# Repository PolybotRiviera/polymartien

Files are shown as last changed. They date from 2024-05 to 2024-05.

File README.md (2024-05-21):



Repo of the robotics project, 2024 edition: Farming Mars,
from the Polytech Nice Sophia robotics team!
## Objectives
The purpose of the robot is to carry out several tasks in complete autonomy. The tasks to be performed are as follows:
- Pick up different types of plant

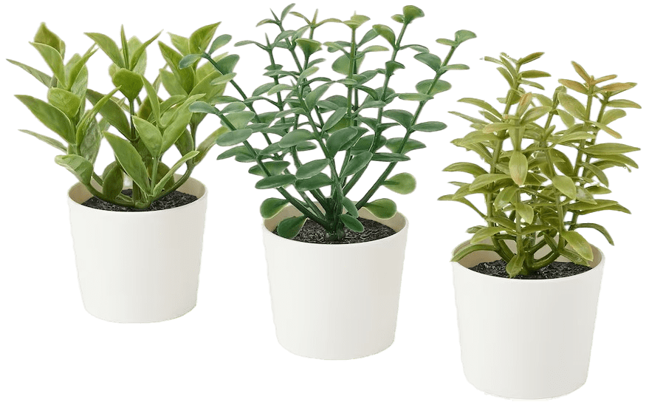
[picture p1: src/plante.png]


- Place plants in pots

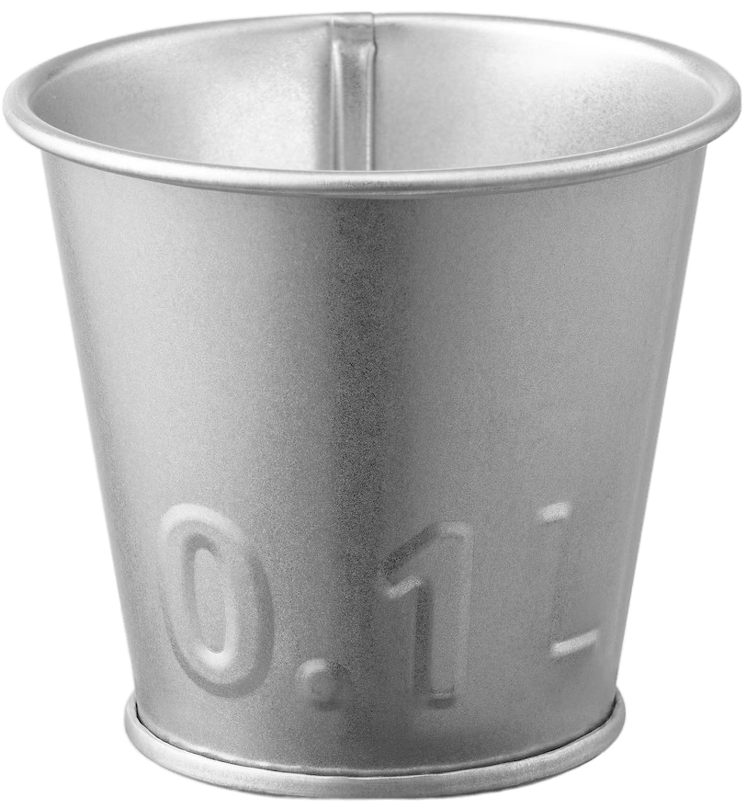
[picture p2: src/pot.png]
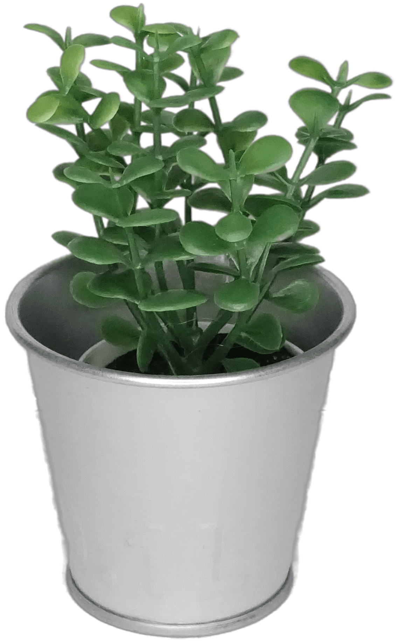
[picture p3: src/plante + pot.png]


- Bring plants to a predefined area

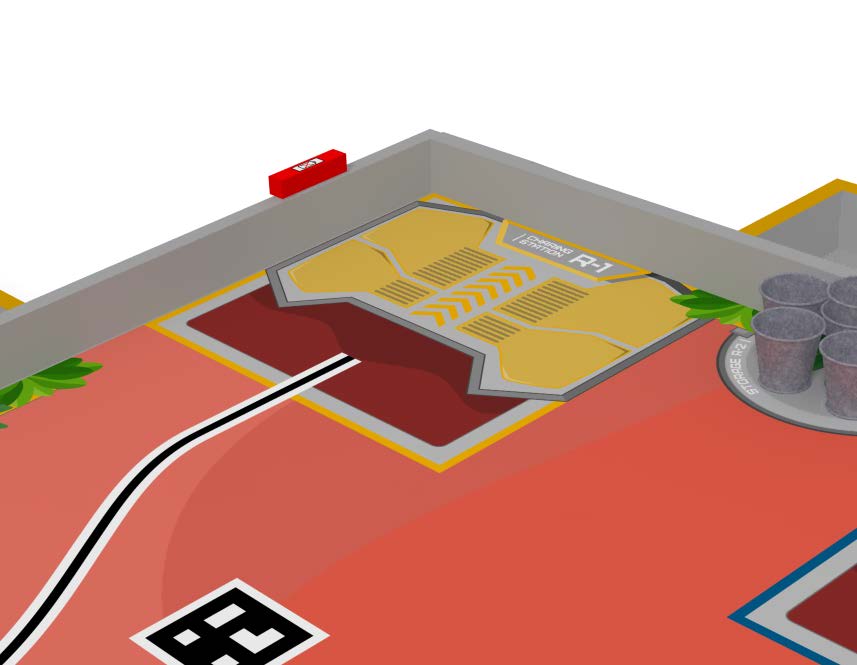
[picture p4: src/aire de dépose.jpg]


- Sort plants by type

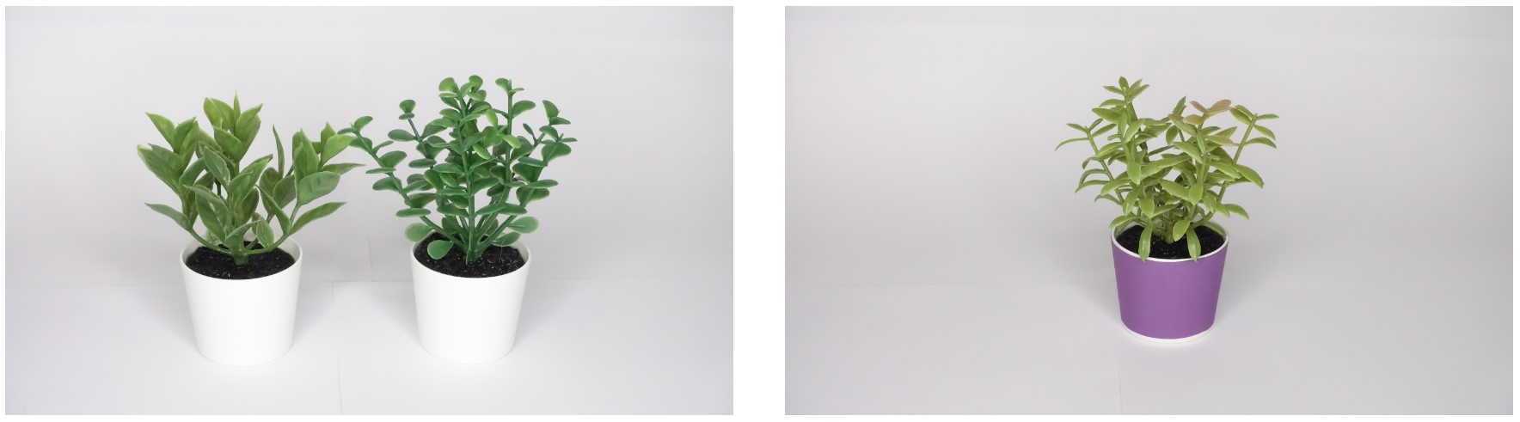
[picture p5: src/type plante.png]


> Two fragile plants, one resistant plant

- Orienting solar panels

All the work must be completed within the allotted time and without colliding with the environment (walls, other robots, plants, pots).

## constraints
- Robot dimensions :
    - Perimeter between 1200 and 1300 mm

    
    
    - Height under 350 mm

## Main components
- Chassis / Rolling base
- Gripper system (rail-mounted gripper)
- Vision systems (cameras, sensors)
- Storage system (turntable)

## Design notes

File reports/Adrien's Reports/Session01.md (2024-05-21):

# Session Report 1:

**Session Objective:** Mount the received DC motors on the prototype, test them, and determine parameters useful for the robot's control.

During this session, we assembled the motors and wheels on the base so that I could initiate the control and odometry of the robot.

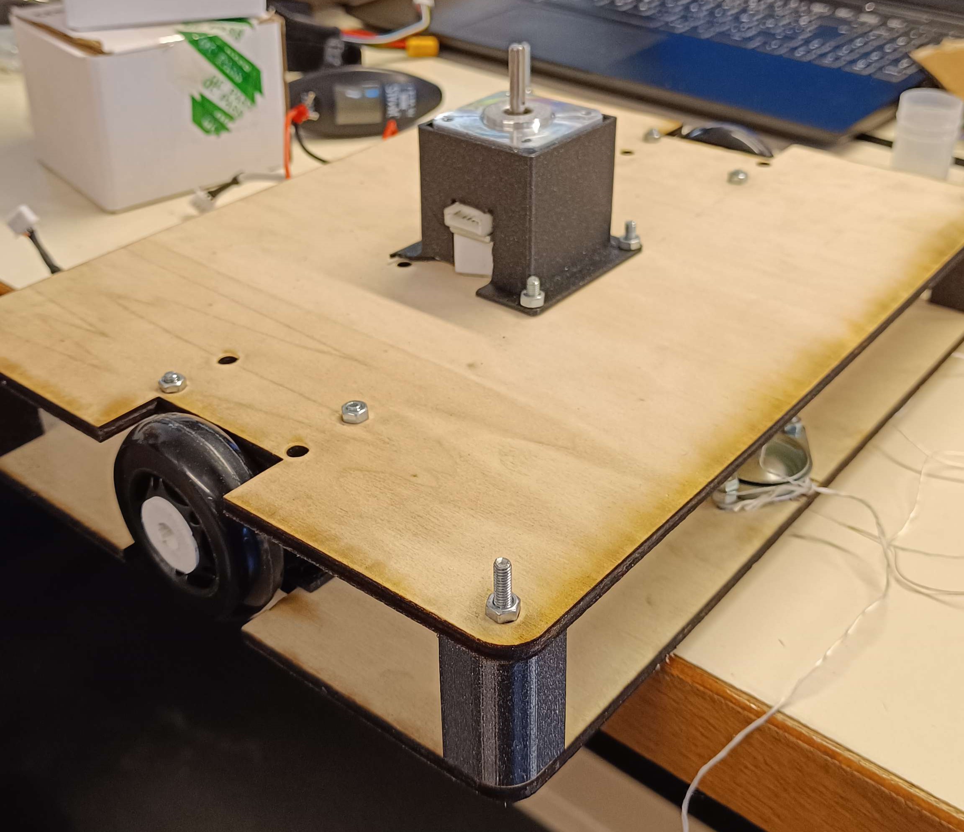
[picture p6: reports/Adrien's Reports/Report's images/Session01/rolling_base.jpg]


## Changes to the Rolling Base:
As mentioned in the project bibliography, the new version of our U-shaped robot has a large empty space in the center to collect plants in large quantities. This efficiency gain adds a significant constraint: we are now obliged to place the motors at the rear of the robot, as shown in the model created by Loïc below.

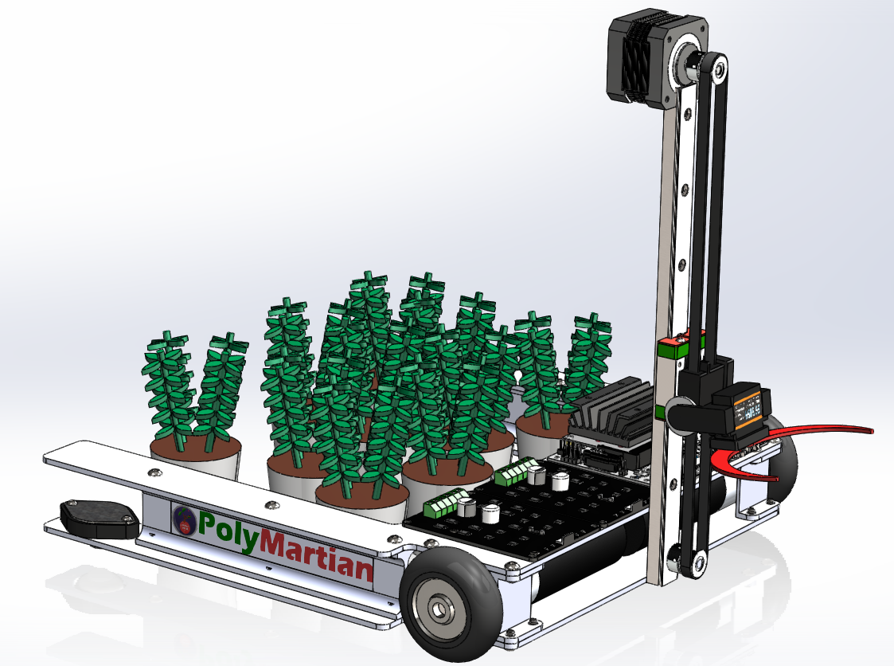
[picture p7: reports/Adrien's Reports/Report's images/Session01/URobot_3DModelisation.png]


However, for the robot to move easily and quickly avoid the opponent robot, it is preferable for the robot to be able to rotate on itself, and therefore have its wheels placed in the middle. Thus, we decided to shift the wheels by transmitting the rotation of the motors placed at the back of the robot to the wheels in the middle using belts.

My research also led me to realize that it would be risky to place encoders directly on the motor axes for robot odometry (i.e., to know its position based on the number of wheel rotations). In the event of robot slippage, the encoder may not be incremented even though the robot has moved, causing a drift in our estimation compared to the actual position. That's why many teams opt for encoder wheels. This involves placing encoders on free wheels parallel to the drive wheels. These free wheels are fixed via a pivot link so that the wheel can always remain in contact with the ground. Finally, the narrower the encoder wheels, the higher the odometry precision will be.

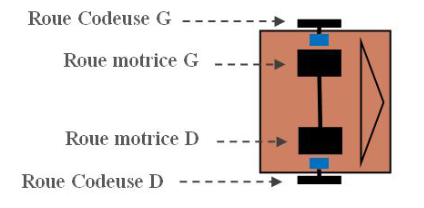
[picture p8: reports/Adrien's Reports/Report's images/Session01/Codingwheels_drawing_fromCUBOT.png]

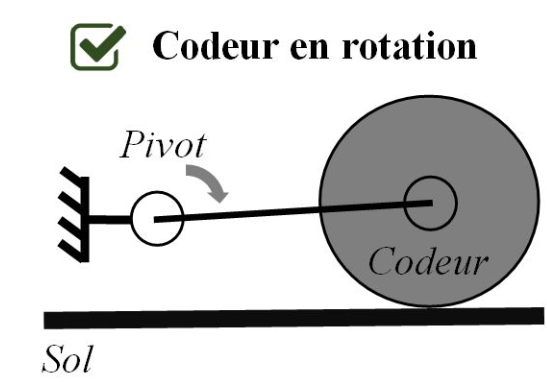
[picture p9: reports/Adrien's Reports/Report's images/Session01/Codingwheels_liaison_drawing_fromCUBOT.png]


(Images Source : Cubot Team)

## Assembly and testing of motors and wheels, and encountered problems:
We were able to test our motors by connecting them using Cytron 13A CC Driver Cards and 12V Power supply.

This revealed a first problem: at high speed, the wheels shake perpendicular to the wheel plane. The most probable hypotheses are that this is due to wheel warping. We ordered roller wheels for good grip, but no precision information is provided on manufacturing tolerance. This will be verified with a comparator before the next session. Another possibility is that the motor axis is not perfectly perpendicular to the wheel axis. Finally, play within the motor can also be the cause, but it is much less than the rotation play of the wheel.

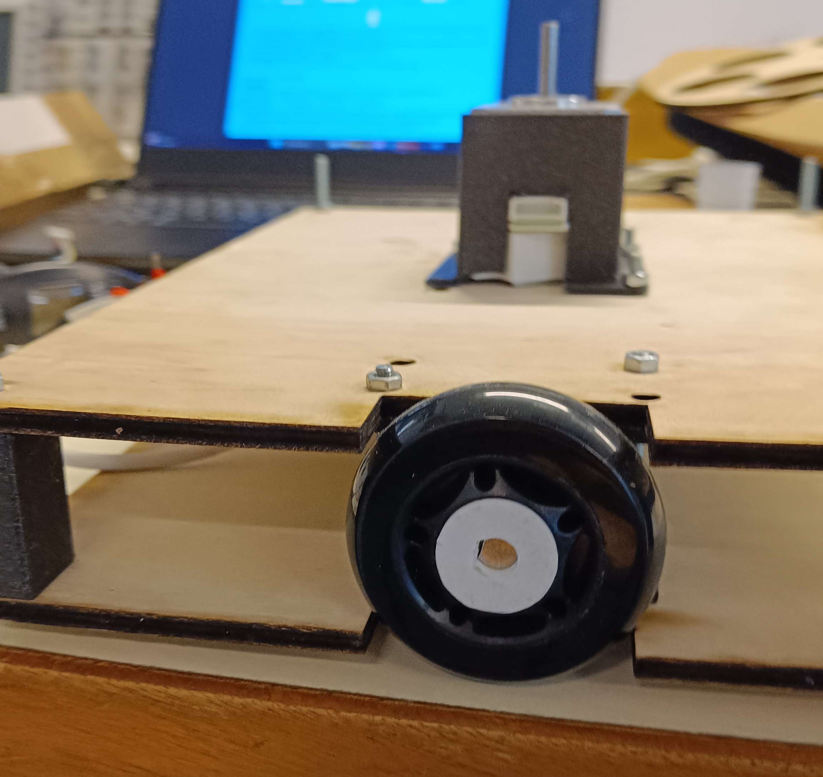
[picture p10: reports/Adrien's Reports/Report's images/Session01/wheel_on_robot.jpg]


## Control: Calculation of the coefficient of adhesion between the wheels and the table.

During this second part of the session, I sought to calculate the coefficient of adhesion of our wheels on the game table to use it in our control parameters. This will be essential (in addition to the center of gravity of the robot) to calculate very precisely the acceleration limit not to exceed under the risk of slipping. Indeed, to optimize acceleration and braking phases, the robot must be at all times at the slipping limit, considering a safety margin.
To measure this coefficient very precisely, the suspended bucket method can be used. This method simply requires a bucket, a pulley, a rope, and a scale.


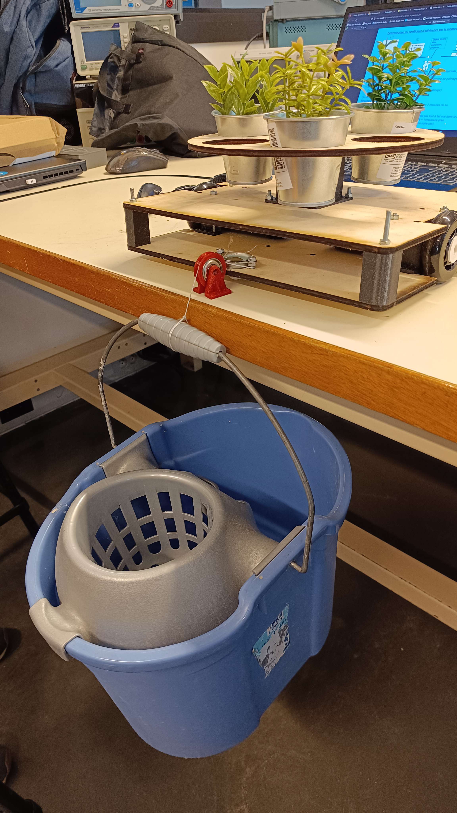
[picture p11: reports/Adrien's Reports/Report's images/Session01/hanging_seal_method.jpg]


It consists of attaching one end of the rope to the base of the robot placed on the table (as close as possible to the base), and the other end to a bucket suspended in the void by passing the rope through a pulley fixed to the end of the table. For this, we simply made a pulley using three 3D-printed pieces and a ball bearing. We then mechanically block the wheels, in our case simply using screwdrivers between the base and the outer surfaces of the wheels. The bucket is then filled with different objects serving as weights to apply a horizontal force on the robot.
To calculate this coefficient, proceed as follows:

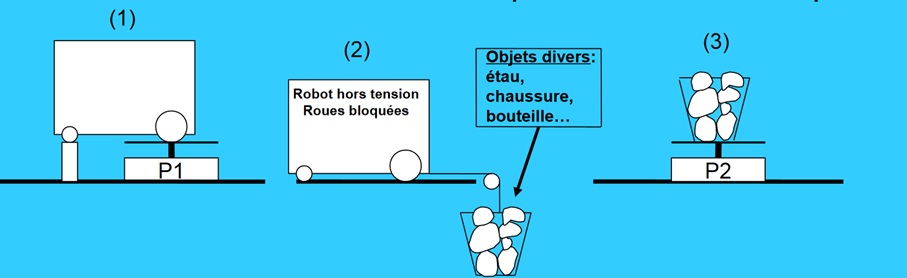
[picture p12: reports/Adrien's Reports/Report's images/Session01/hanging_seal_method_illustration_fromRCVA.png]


(Image Source : RCVA Team)

- Measure the support force of the drive wheels on the ground by placing the robot wheels on a scale while keeping it horizontal with a wedge under the free wheel. Note this mass P1.
- Measure the mass of the objects in the bucket from which the robot is at the slipping limit, i.e., the force required to slide the robot with the wheels blocked. Note this mass P2.
- Finally, the coefficient is simply Ka = P2/P1.

Due to measurement inaccuracies (due to the choice of weights), you can calculate both the robot's adhesion coefficient unloaded and loaded and keep the average of the two. Indeed, the coefficient of adhesion is theoretically the same unloaded and loaded.

Having received the official vinyl game mat, we wanted to calculate the coefficient of adhesion between the wheels and the mat during this session. 

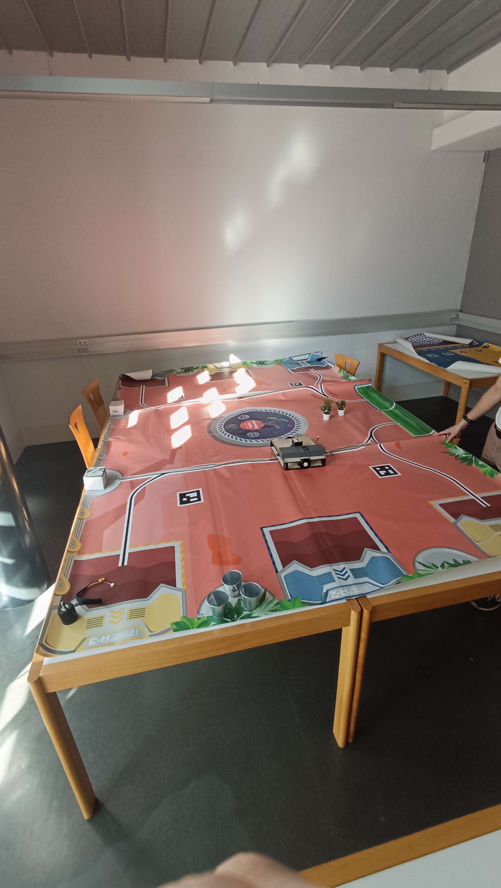
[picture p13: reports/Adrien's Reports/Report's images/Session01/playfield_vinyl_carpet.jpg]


However, our scale was limited to loads of 2 kg, so we have to postpone this calculation to later. However, this allowed us to observe the very strong adhesion of the roller wheels on the vinyl and to manufacture the suspended bucket system that will be used later.

## Sources:

    http://www.rcva.fr/wp-content/uploads/2016/12/devoir_de_vacances.pdf
    https://github.com/VRAC-team/la-maxi-liste-ressourceseurobot/blob/master/asservissement/Cubot-atelier_asservissement.pdf

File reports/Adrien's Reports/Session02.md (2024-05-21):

# Session report 2:

**Session objective:** Complete research on the most crucial physics constraints to consider in achieving a reliable rolling base for the prototyping of the next version. And begin work on the closed-loop control.

## Steps to implement odometry and feedback control 

First of all, I established an ordered list of my next tasks to do to enhance efficiency:

1) Ensure a high-performance mechanical system with optimal weight distribution, reliable coding wheels, and precise wheel placement. This aspect was thoroughly considered since we started the first session. We have now identified an excellent implementation, and Loic is currently working on the mechanical part.
2) Calibrate the odometry to determine the precise location of the robot on the table using the coding wheels. This system relies on four constants: coding wheel diameters, their spacing, encoder resolution, and the error related to the diameter difference between the two coding wheels.
3) Send a command and calculate errors between it and the estimated position based on the odometry.
4) Implement ramps to achieve progressive acceleration and deceleration.
5) Implement a PID (Proportional Integral Derivative) control system: Identify the optimal coefficients for Proportional, Integral, and Derivative terms to reach a value very close to the setpoint rapidly and without excessive oscillations.

As the coding wheels are still in the design phase, I have decided to prioritize continuing work on determining the maximum acceleration. This way, this aspect will be prepared for implementation once the rolling base is ready to conduct physics measurements.

## Measuring the buckling of the wheels and the play in the motor.

During the previous session, we observed lateral vibrations in the wheels. Therefore, this time, using a dial indicator, I measured the buckling of the wheels.

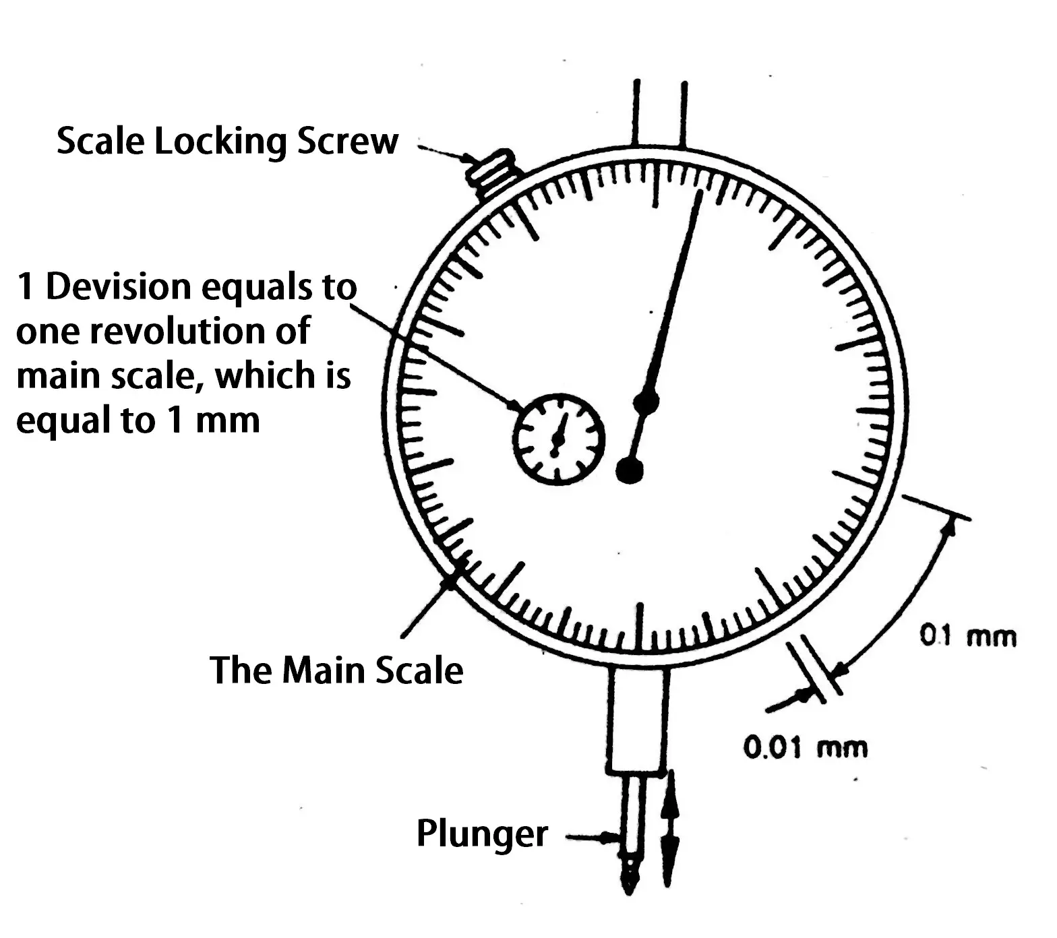
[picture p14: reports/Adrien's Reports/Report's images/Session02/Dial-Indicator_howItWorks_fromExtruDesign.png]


To use this tool, we have to magnetize it to a fixed surface to prevent shaking. Then, we simply position the plunger against the external surface of the wheel. Next, we delicately turn the wheel one complete revolution (or multiple turns for more precision). Afterward, we read the buckling on the graduated scale and divide it by the number of turns made. The precision of this instrument is approximately 0.01mm, which corresponds to the space between two marks on the scale.

With this tool, I measured a buckling of approximately 1mm per wheel, which is not insignificant but much less than I expected. Therefore, I believe it won't pose a significant obstacle to achieving precise odometry at the outset. That's why we have decided to retain these wheels, and we will consider replacing them with more precise ones only if they prove inadequate results.

## Encoder and reflections on coding wheels

Since the encoders attached to the ends of our motor shafts are now no longer needed due to the use of coding wheels. I have contemplated a way to repurpose these encoders by placing them in front of the metal shafts of the coding wheels to avoid buying new ones. By disassembling one, I observed that we could easily reduce the total length of the motor + gearbox assembly to position the wheels more toward the inside. This will allow us to align the coding wheels in parallel on the extremities of the robot. Indeed, the greater the spacing between the coding wheels, the more precise our angle reading during rotation will be. Additionally, since the encoder is a Hall effect sensor, we can easily reuse it by placing the hall sensor directly in front of the axes of our rotary encoders.

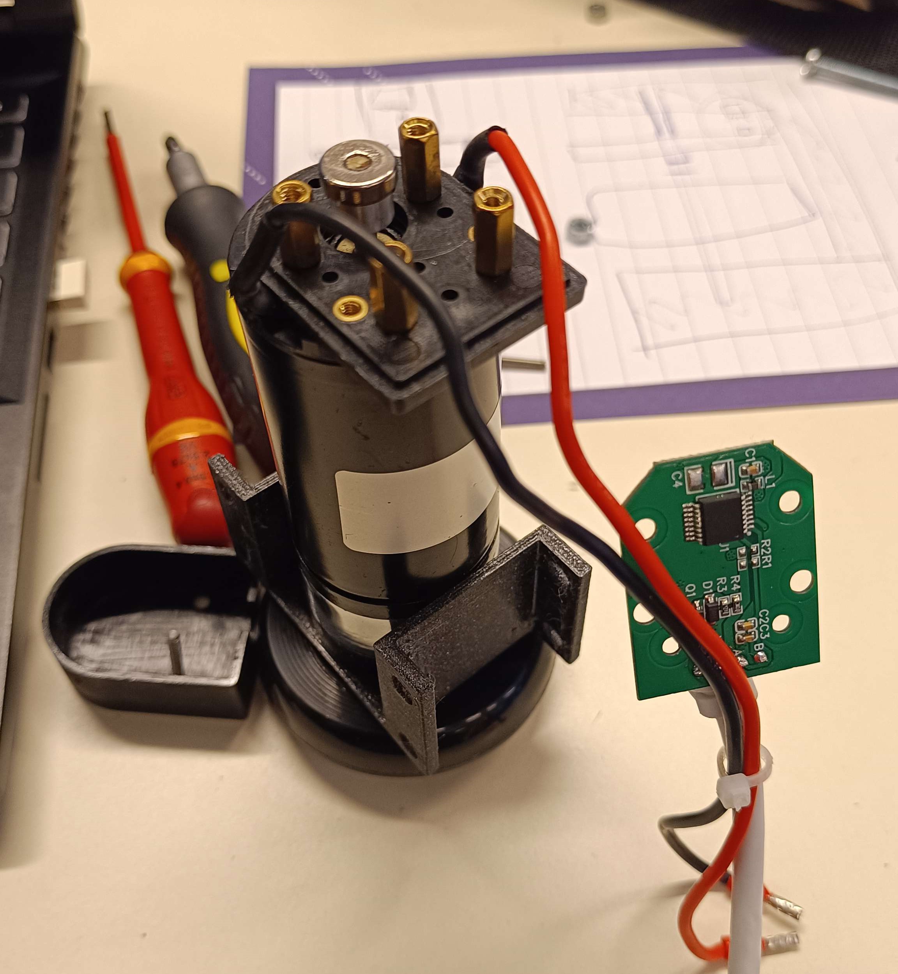
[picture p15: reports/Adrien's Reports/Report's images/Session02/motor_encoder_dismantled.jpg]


During this session, I also learned that a minuscule diameter difference between the two coding wheels can result in significant imprecision. Cause if the coding wheels register the same number of revolutions, it will lead us to believe that the robot is moving in a straight line. However, in reality, if one wheel has a smaller diameter, the robot will veer to one side.

And as we integrate small displacements of the robot to determine the position from a reference point. We will accumulate erros over time which will be source to a lack of precision.

To address this issue, we need to implement a coefficient to multiply the number of revolutions of one wheel by a certain factor. This compensates for the diameter difference, ensuring that both wheels cover an equal distance and register the correct movement.

## New conception for the rolling base with its coding wheels

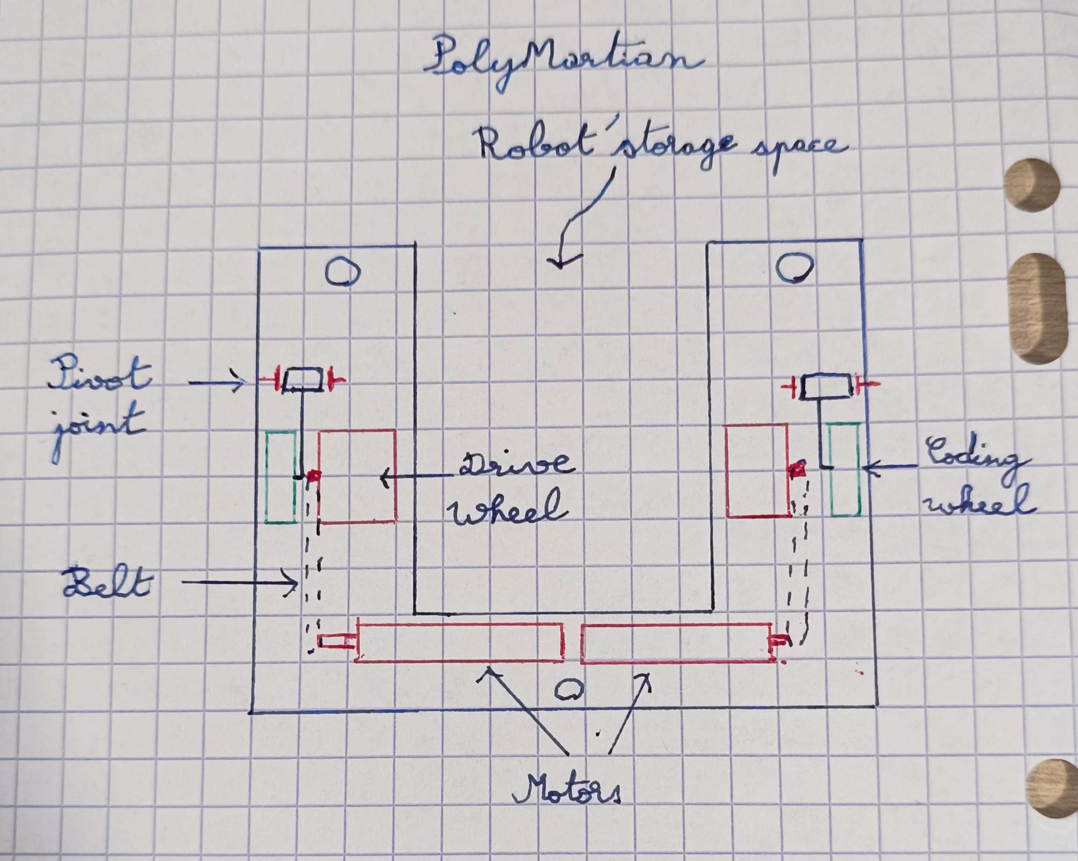
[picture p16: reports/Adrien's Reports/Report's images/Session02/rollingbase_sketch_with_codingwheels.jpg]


I designed a diagram of the new rolling base to determine how we will position our coding wheels, motors, and drive wheels. To place the wheels in the middle of the robot, we chose to use belts to transmit the rotation of the motors, which are positioned at the back of the base. This decision was influenced by our choice to store plants at the center of the robot, leaving only the back for motor placement.

As explained earlier, the coding wheels are positioned in parallel to the driving wheels at the extremities to achieve a large center-to-center distance. Each coding wheel is mounted on the base with a pivot joint to ensure constant contact with the floor. Finally but not least, we have incorporated three freewheels for enhanced stability in the robot.

##**Next session tasks:**

During the next session, I will continue preparing the robot displacement and odometry algorithms, as well as the necessary calculations, to be ready to begin work on the robot's position. If the new rolling base prototype, including the coding wheels, is ready, I will initiate the odometry calibration.

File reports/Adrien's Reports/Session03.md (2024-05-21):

# Session report 3:

**Session objective:** : 
- Assemble the solar panels (game accessories) in preparation for manufacturing the playfield.
- Develop the closed-loop motor control algorithm.

## Assembly of the 9 solar panels

The playfield for the competition comprises 9 elements referred to as "solar panels." These panels are arranged along one border of the table and these elements feature 2 colors : blue and yellow. The objective for the robots is to rotate as many solar panels as possible, aligning their team color towards the inside of the table to score points. Each solar panel consists of two 3D-printed parts, a vinyl cut, a screw, a nylstop nut, and a washer.

To meet the competition regulations, I initially sliced the 3D parts, adhering to the specified parameters outlined in the rules. It is crucial for our models to conform to similar weights and dimensions, ensuring approval by the regulations. This uniformity allows us to replicate the competition conditions with precision.



That's why I notably needed to modify the fill density to 40% and the fill pattern to 'Cubic'.



Then, to assemble the two 3D-printed parts, I used a CHC M6*50mm screw with a Nylstop Nut, and placed a washer between the two parts to reduce friction, following the instructions in the plan. This assembly allows rotation between the 2 pieces.

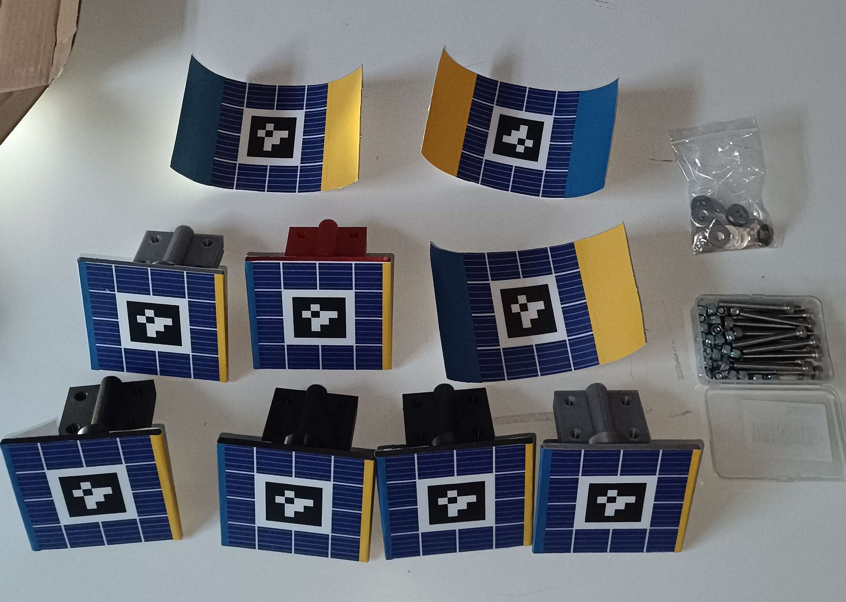
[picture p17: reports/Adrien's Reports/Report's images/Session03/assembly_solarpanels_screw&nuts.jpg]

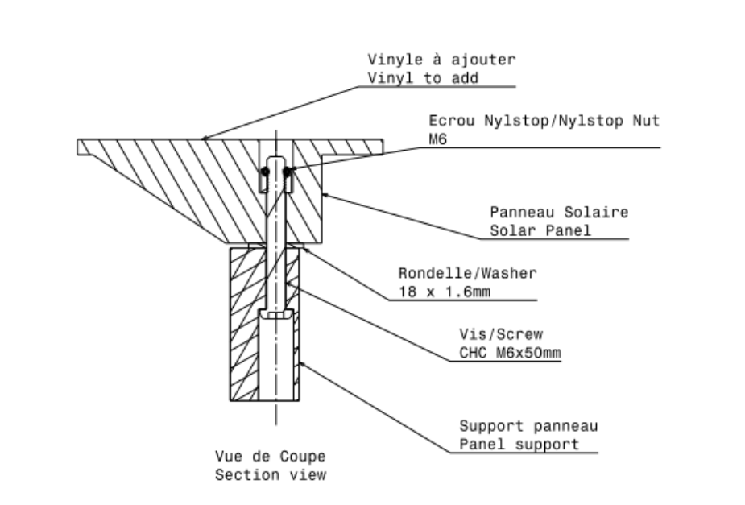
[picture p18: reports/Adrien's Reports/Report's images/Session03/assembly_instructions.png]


The main difficulty was that the nut was spinning freely when I tightened the assembly. Therefore, I had to wedge a flathead screwdriver between the plastic part and the nut while screwing.

Then, I cut our vinyl using a cutter to detach the shapes of the solar panels and glued them onto the 3D-printed part, ensuring the correct orientation.



Finally, here are all the nine solar panels ready to be affixed to the table.

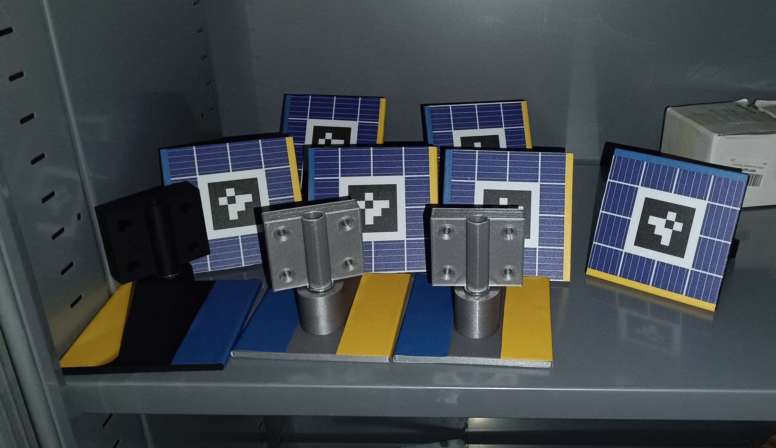
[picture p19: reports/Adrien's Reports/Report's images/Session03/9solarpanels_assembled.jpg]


## Programming the closed loop control

Finally i prepared an algorithm to control motors with a closed loop regulation. The commented code will be available on the github but here are some important points to understand it better : 

We define encoder pins as "INPUT_PULLUP" so if there is no signal on this pin, we will receive the value 1 and when we will reveive something it will be 0.

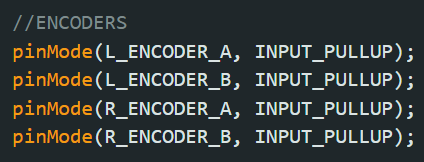
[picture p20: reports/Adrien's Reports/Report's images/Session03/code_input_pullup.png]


Then we will use interruptions so each time there is a changement on one of the left or right encoder pin, we will call the associated interrupt functions.



Finally as each coding wheel has a little diameter difference, we will never have the same number of tick per cm on each during translations and rotations. That's why we introduced the following variables : 

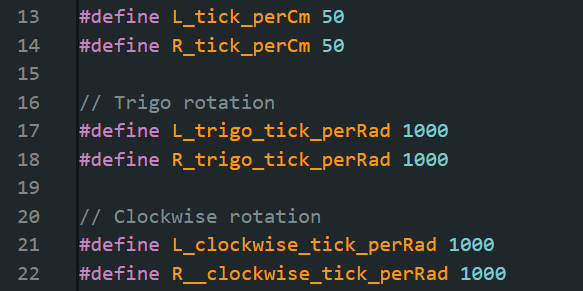
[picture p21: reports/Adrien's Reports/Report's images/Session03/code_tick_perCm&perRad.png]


The rest of the code with the pid regulation and odometry is well commented and available on the github.

## **Next session tasks:** 
Test the closed-loop control algorithm on the robot and select appropriate coefficients to estimate robot's position and to have a correct trajectory

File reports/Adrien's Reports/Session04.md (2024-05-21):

# Session report 4:

**Session objective:** Test the algorithm I wrote during the previous session, fix bugs, and implement new functionalities.

## Issue with serial speedrate

First of all, I had a significant issue with the code's execution speed. The algorithm slowed down because of the communication speed, which was only 9600 bits per second. The Arduino couldn't sustain the motor pins at high levels while printing the number of ticks from the encoder on the serial connection at this speed. I resolved this by initializing the communication speed to 115200 bits in the Serial.begin().

## Receiving commands from the monitor



Then, I implemented a function that enables sending commands to the robots from the monitor using serial communication. I created a list of characters which will contain the command.

Whenever a character becomes available in the buffer, we read it and add it to the first empty position in the list (thanks to the increasing index position_character). When this character is a line break, we call a function that will parse the command.

# Parsing the command to get input parameters

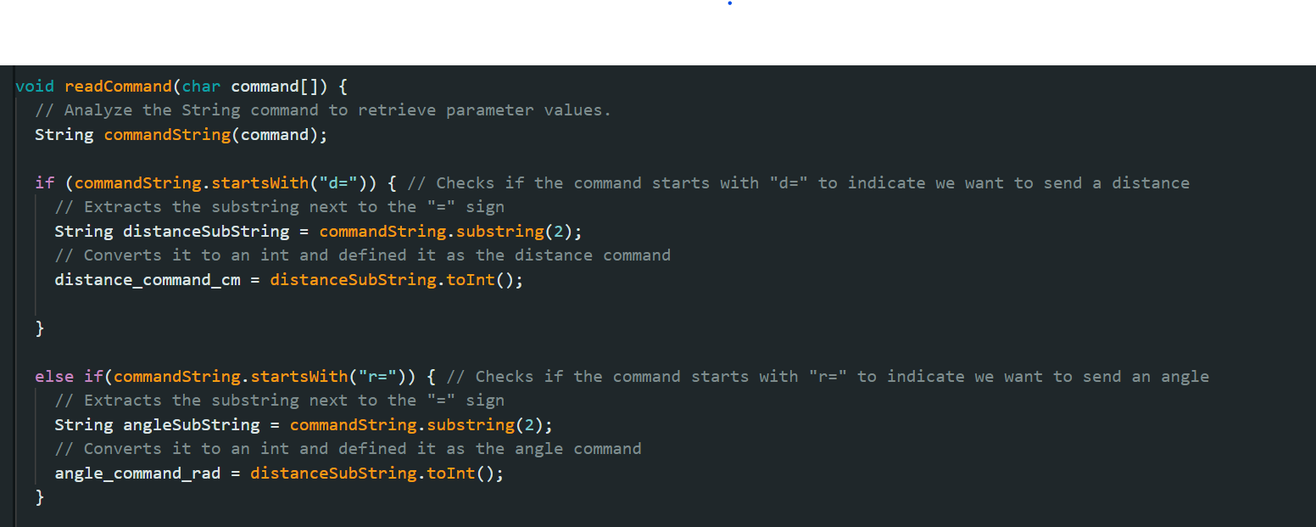
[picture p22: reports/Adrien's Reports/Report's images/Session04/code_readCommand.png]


To parse the command, we compare the first characters with the expected results. Thus, if the first characters are "d=", we expect that the next characters, when converted to an integer, will represent the distance command. Similarly, if the first characters are "r=", it indicates that the subsequent characters will represent an angle value.

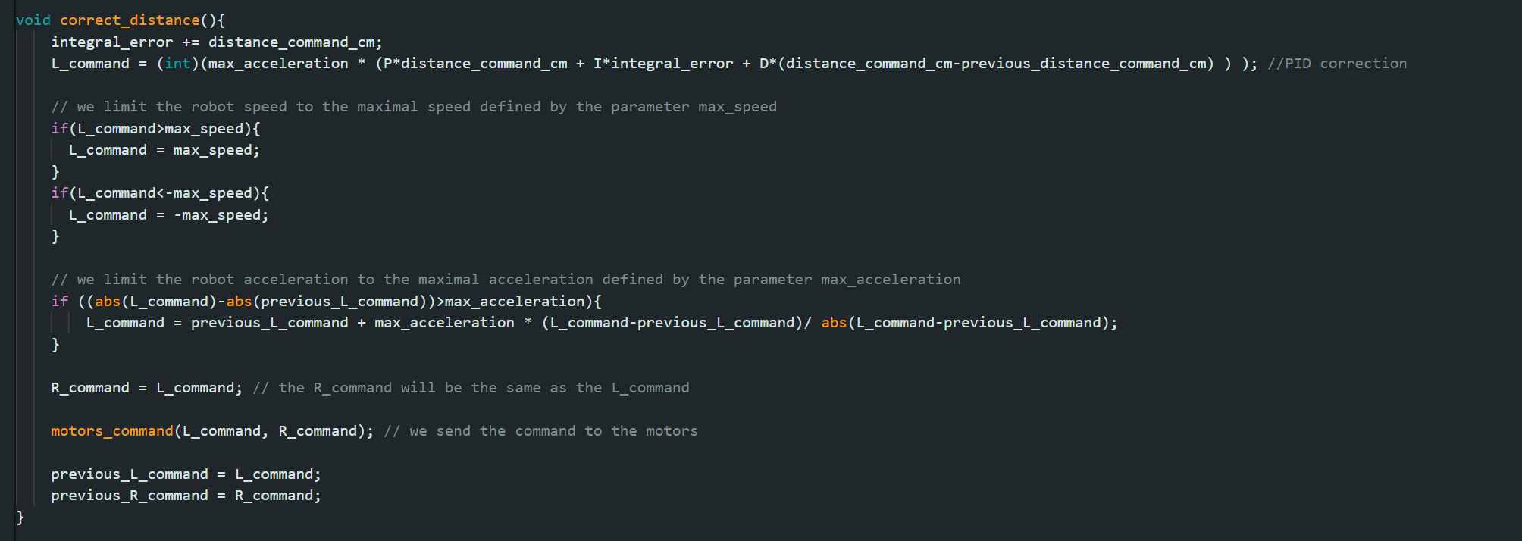
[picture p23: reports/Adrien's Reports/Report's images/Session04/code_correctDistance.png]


Finally, we have two error correction functions—one for correcting distance and another for correcting rotation. These functions will be called each time we acquire new measurements from the encoders. Both functions are very similar and based on the same principles. I will explain the correct_distance function.

Firstly, we apply the PID coefficients to the command, which has been calculated based on the difference between our previous command and the real position of the robot (refer to Session03 report). To achieve this, we increment the integral error with our new command. Subsequently, the command is simply equal to our PID correction at the maximum defined acceleration. We then check if this command is less than our maximum speed and if our acceleration is less than the maximum acceleration. If not, we limit it to our maximum values. The commands for the left motor and right motor will be the same because we correct the trajectory's orientation using the correct_orientation function.

Finally, we send our commands to the two motors using the motor commands function and we save our actual commands as previous commands.

## **Next session tasks:**

Before the next session, we should have completed the assembly of the new rolling base. This will enable me to implement my algorithm on the robot and calculate PID coefficients.

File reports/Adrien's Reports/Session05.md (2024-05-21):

# Session report 5:

**Session objective:** Assemble the pivot joints of the coding wheels and place the encoders in front of their axis.

To ensure continuous contact between our coding wheels and the ground, we opted for a pivot joint between the wheel and the rolling base, equipped with holes to attach an encoder using spacers. During this session, I began assembling the joint designed by Loic in the previous sessions.

## Recover the spacers and magnets initially present at the end of the motor shaft.

Firstly, I dismantled the encoders to reposition them in front of the coding wheels, aligning with our new design. Initially, I retrieved the spacers from the encoders, which will be reused to position them in front of the coding wheel axis.

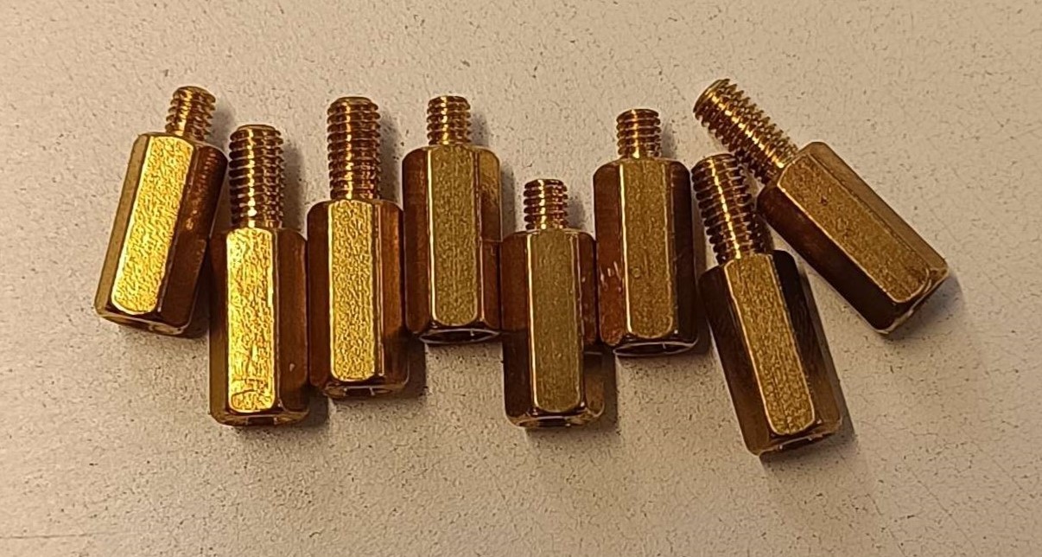
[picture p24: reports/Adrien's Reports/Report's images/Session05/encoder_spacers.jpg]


Next, I dismantled the magnets from the ends of the two motor shafts (as circled in the photo) because we will need them in front of the encoders' new positions.

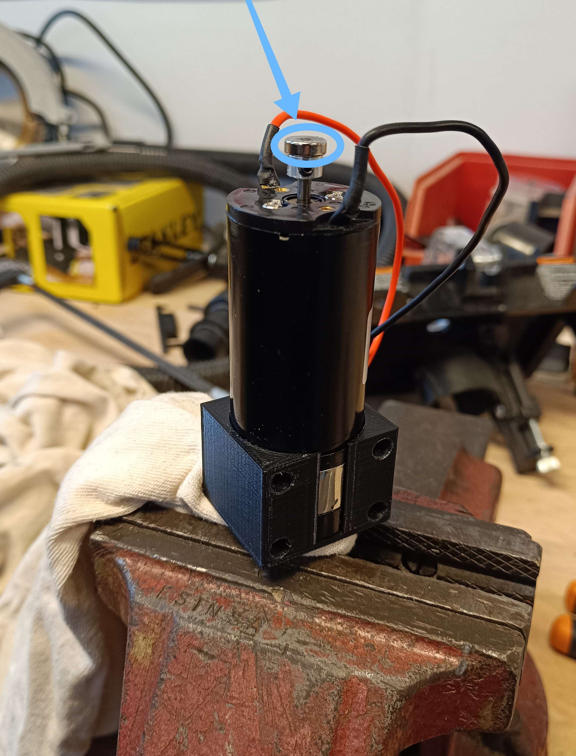
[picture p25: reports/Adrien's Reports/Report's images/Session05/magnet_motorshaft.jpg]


This was very challenging because the magnets were likely assembled while hot. As I needed more strength to remove them, I attempted to use pliers as a lever, but it didn't work. Eventually, I resorted to using a vise to firmly hold the motor by its lower shaft, preventing any damage to the motor shaft, while using another pair of pliers to stop it from turning on itself. After a considerable amount of time and with some assistance, I finally succeeded in recovering the magnets, even though one broke in the process.



## Modeling and 3D printing a component for assembling magnets and metal rods together.

We needed to position the magnets we recovered at the ends of our coding wheel metal rods. Gluing them together didn't seem like the best solution due to the rotational speed of the coding wheels. Losing the magnets during the competition would be dramatic, as it would prevent us from correcting our trajectories and tracking the robot's localization. Therefore, I decided to create a small 3D-printed part that will be used as a flush-link connection.

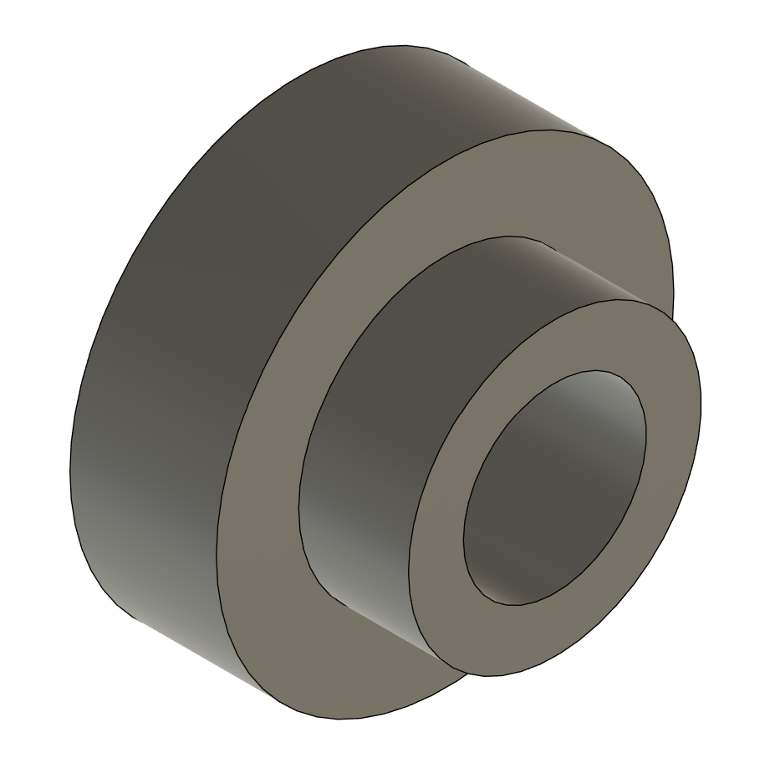
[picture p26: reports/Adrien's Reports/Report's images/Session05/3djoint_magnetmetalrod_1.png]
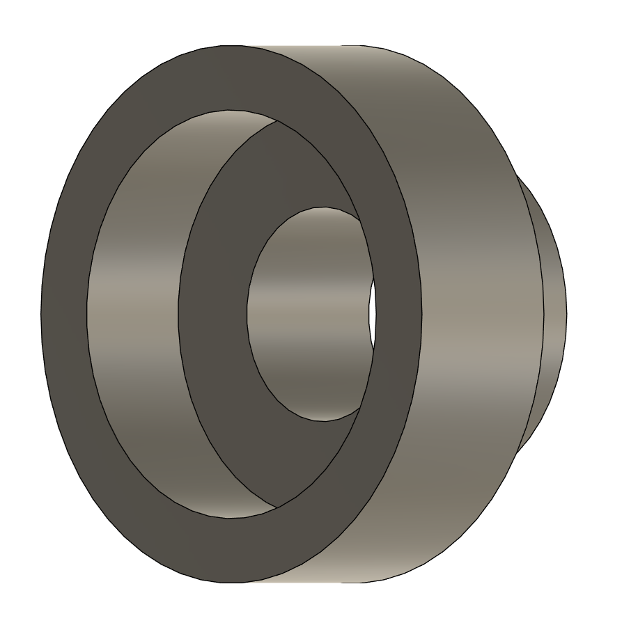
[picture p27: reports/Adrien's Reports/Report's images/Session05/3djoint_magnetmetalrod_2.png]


Each part is forcefully inserted into a hole in the plastic component with zero tolerance. To enhance the fixation, we will even apply glue to the plastic part.

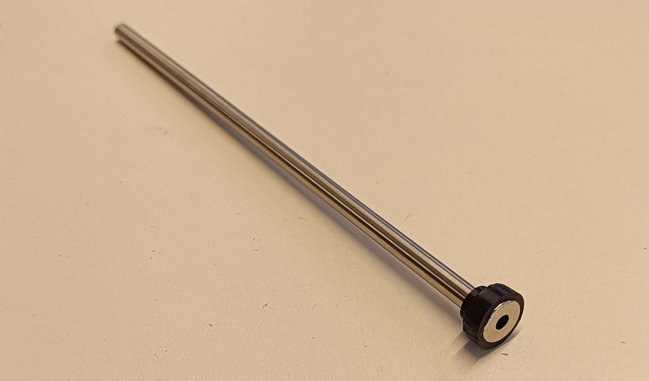
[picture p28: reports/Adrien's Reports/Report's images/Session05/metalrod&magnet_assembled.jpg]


## Cutting an aluminum rod to use it as an axis for the coding wheels.

Finally, I cut the rod into two parts of 15mm each using a hacksaw, so their length will be perfectly adapted to fit with the coding wheel pivot joint thickness.

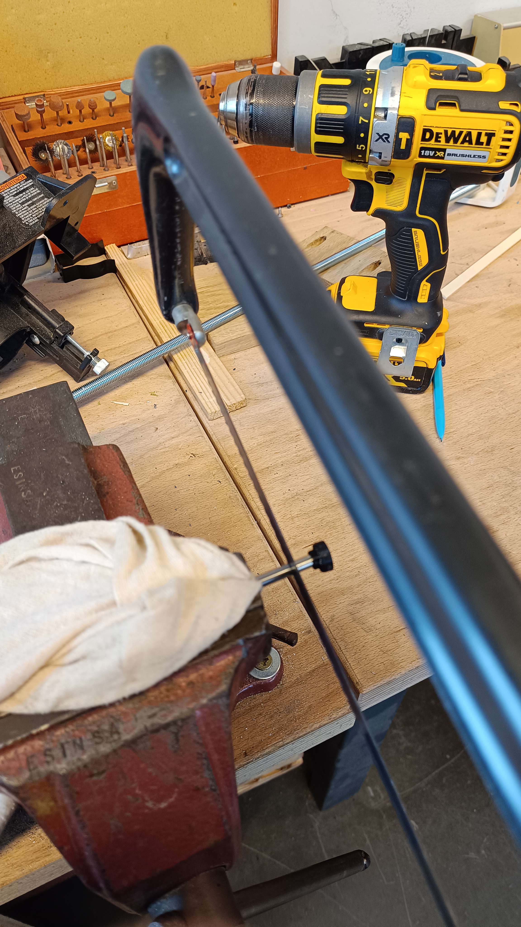
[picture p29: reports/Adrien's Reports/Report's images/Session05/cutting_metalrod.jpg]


I also smoothed the cut surfaces with a metal file.

## **Next session tasks:**

In the next session, I will complete the assembly of the coding wheel fixation. If our rolling base is ready to move, I will test our algorithm to begin determining our PID coefficients.

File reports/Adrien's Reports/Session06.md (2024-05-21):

# Session report 5:

**Session objective:** Test the rolling base with assembled belts, complete the assembly of the coding wheels, and then test them.

## Belts not strong enough.

First of all, after Loic finished assembling the belt transmissions, we tested the rolling base on the ground. However, one belt broke directly due to the starting torque of our motors. As a result, we concluded that sewing the belts might be risky in such a competition. To address this weakness, we identified some belts with the desired length that are already a closed loop, eliminating the need for sewing.

## Assembling the wheels with encoders.



Then, after I finished placing the encoder magnets in their 3D printed support, each of us assembled one coding wheel.

The assembly is mounted on an aluminum shaft cut to the desired size. It includes the wheel, an arm, and the 3D printed part that holds the magnet, with washers between them, all assembled by force with no tolerances. The encoder is mounted on the arm using the initial spacers and screws.

Then I mounted the other part of the arm on pivot connection on the rolling base with a bolt and washers. 



## Testing the encoders

I used the code I wrote previously to test the encoders on the coding wheels. I achieved a really good result for the left wheel, but the encoder of the right wheel was continuously detecting a variation in the magnetic field. As a result, the distance traveled by this wheel was increasing even when the wheel wasn't spinning.

At first, I thought it was due to a poorly fixed encoder that might be moving due to vibrations. However, even after correctly securing it, the results only slightly improved. I came to the conclusion that it was due to the magnet we broke, which was now made from three distinct parts glued together.

After some research, I discovered that because the magnet is broken into three parts, the fragmentation could lead to irregularities in the field, causing issues with the encoder's readings.

I tried replacing this magnet with a neodymium magnet I found, but the results were peculiar. On one side of the magnet, the encoder detected no variation, while on the other side, the encoder detected a significant variation even when the wheel wasn't spinning. 
I had a correct result only when placing the side of it in front of the hall sensor, which isn't the result desired.

Since our original magnet had a hole in the center, I wondered if this had an influence on the magnetic field. To verify this, I attempted to drill a hole in the new magnet using a drill press. However, it was challenging to keep the drill perpendicular without creating a specialized support.

 Original Magnet

-

 Tested Magnet

To grasp the issue, I delved into understanding the precise workings of an encoder. A magnetic encoder detects rotational position changes through variations in the magnetic field. As the motor shaft's attached permanent magnet rotates, the magnetic sensor registers shifts in the magnetic field. But there are different way of magnetizing a magnet : it can be with a radial direction or axial direction as explained below.



The Hall element is positioned in an area where the horizontal magnetic field is uniform. So in front of a planar face with our original magnet.

This is likely the reason why our encoder wasn't detecting variations on our new magnet.

Since I couldn't find any documentation detailing the characteristics of the encoder's magnet for purchasing a replacement, I opted to contact the seller to inquire about this information. Eventually, they agreed to sell a new one independently.

## **Next session tasks:**
Once we receive the new magnet and the appropriate belts, our rolling base should be complete. I will then proceed to test it, make any necessary improvements, and begin the process of determining the PID coefficients.

## Sources 
https://www.akm.com/eu/en/products/rotation-angle-sensor/tutorial/magnetic-encoder/

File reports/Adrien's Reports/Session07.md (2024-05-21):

# Session report 7:

**Session objective:** Finishing the creation of the playground to test our robot in competition conditions, assembling the driving wheels and encoding wheels with our new belts and springs.

## Estimating the amount of wood we need using leftover pieces of wood.
First of all, I created an Excel document to calculate the quantity of wood needed in terms of surface, following the competition specifications, to construct all the borders and planters for our playground. To save money and be eco-responsible, as suggested by our FabManager, we used reclaimed wood kindly provided by the association 'Atelier Riviera Carpenters Grasse,' whom we thank for their help.

## Cutting the borders of our table
Then, we had to cut wooden boards into 13 pieces of the required length to create a border surrounding the 3 x 2 meters table. To do that, I learned how to use an under-table circular saw, adjusting the saw height and position with the included ruler to cut the desired length. Due to the risks of potential injury, I used it under the necessary supervision of a professor from the Fablab. Furthermore, it was necessary to wear a noise protection helmet and use a tool to push the wood under the saw without approaching hands too closely, while keeping one hand near the emergency stop button.

## Fixing the borders on the table
Finally, with another member of the team, we attached the borders to the table and measured the dimensions needed to fabricate the planters. 



Similarly, they were cut with a circular saw and then assembled with screws on the sides.



## Replacing the defective magnet with new one we ordered
As explained in the previous report, our damaged magnet was not producing the same magnetic field as when it was new, so I had to order a new one with the same magnetic field. Consequently, I replaced the damaged one with the new one after 3D printing a small part to hold it. I then reassembled all the components on the wheel shaft with fixed joints.



## Minimizing the play in the wheel assembly.
Last but not least as our wheel shaft was rubbing against our encoder, I minimized the play in our wheel assembly to allow more space between our wheel assembly and encoder avoiding damaging it gluing a loose ball bearing. 



Then we assembled the robot and we tested our rolling base with new belts, everthing works perfectly.




## **Next session tasks:**
Now that our rolling base is complete and fonctionnal, i will be able to implement the Proportional Integral Derivative (PID) algorithm i wrote so i will spend the next hours finding the correct coefficients and fixing bugs in the algorithm to be able to control precisely the robot and know perfectly his position. We will also glue the play mat to the table and fix planters and solar pannels to the playground table.

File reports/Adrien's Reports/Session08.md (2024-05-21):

# Session report 8: February 07, 2024

**Session objective:** Assemble the playground table, calibrate the robot's odometry, fix bugs in the algorithm, and test the robot on the ground.

# Before the session :

## Completing the assembly of our replica of the competition's playground.

Now that our five wooden boards and borders have been assembled, we were able to install planters and solar panels on the outside of the borders. To accomplish this, we, along with another team member, placed marks where the installations were needed as specified in the competition rules. For the planters, we utilized an angled drill guide, enabling us to securely fasten screws at an angle between the two wood planks.



After completing most of the assembly, we were not yet prepared to apply the self-adhesive carpet because the planks were not perfectly aligned, which would result in significant bumps after installation. To address this issue, we added more screws to the smaller planks between the larger ones beneath the table. This adjustment was necessary as our previous screws were not positioned closely enough to the separations to prevent bending.



## Applying the self-adhesive playmat.
Before applying the carpet, we cleaned the table with a cloth and soap, followed by 90° alcohol, to eliminate all dust particles. Indeed, even a tiny particle can create a visible bump on the carpet.



Applying the three distinct self-adhesives took more than four hours, requiring three people to ensure proper installation. One person used a spatula to adhere the carpet, another stretched it on the opposite side, and the last one removed the sticker from the bottom. Achieving the desired result involved a slow and meticulous process, restarting each time a dust particle or large bubble appeared beneath the carpet. Unfortunately, the self-adhesive carpet did not have the correct specified dimensions due to a manufacturer's imprecision, resulting in incomplete coverage of the table.

I would like to thanks Frederic Juan from our school's Fablab for his help.

Here is the final result : 



## Final issue with the encoder
During my tests, one encoder's values were still oscillating even when the wheel wasn't moving. To resolve this issue, I simply adjusted the position of the magnet, moving it closer to the encoder. Additionally, I inserted washers between the magnet and other components to minimize backlash, which was causing vibrations.



# During the session : 

## First ground test of our robot.
To test the robot, I temporarily connected all the electronics, including a 24V battery, Cytron drivers, and the Arduino with rilsan collars. However, due to the weight being positioned at the back of the robot, its wheels were slipping, causing it to roll improperly. To address this issue, I added counterweights at the front of the robot to ensure proper ground adherence. (I temporarily used some boxes of screws for this purpose).



## Performing robot calibration.
Subsequently, I conducted a test of my algorithm. Initially, I calibrated the robot by measuring the number of ticks per centimeter and per radian. To achieve this, I placed the robot on the ground and manually moved it alongside a one-meter ruler in a straight line. After covering one meter, I read the number of ticks received by the Arduino and divided it by 100 to obtain the number of ticks per centimeter.



For rotation calibration, I rotated the robot 360 degrees, and then divided the obtained value by 2*Pi to determine the number of ticks per radian. 

This calibration enables me to calculate the distance traveled by the robot based on the number of ticks and correct our position until the desired one is reached. However, this method is not very precise, so we plan to soon manufacture a removable support that will be screwed onto the robot. This support will have a hole at the center of kinetics, allowing us to attach a board with a nail underneath the robot. This will enable us to rotate the robot in a perfectly circular manner.

Here is the result in rotation : https://youtube.com/shorts/9qRIA3YaiO8?si=xRvWADhP5XFraYfz

Here is the result in translation : https://youtube.com/shorts/vkulLAi6vmk?si=7tIgm1-a3TSwJvxI

These results were obtained without utilizing PID correction, only employing a basic corrector.

## Incorporating PID coefficients and implementing techniques to prevent oscillations.

Subsequently, I introduced PID coefficients into our error calculation. However, determining these coefficients proved challenging, as the robot's weight is soon to be modified with the addition of new actuators, electronics, and power supplies. This modification will significantly alter our correction coefficients.

Additionally, I came across a technique to prevent excessive oscillation around the desired value, thanks to videos from the YouTube channel 'Robot en carton.' The integral coefficient is employed to catch up with the robot's position. However, to avoid exceeding our target too much, we can set this coefficient to zero if the remaining angle to achieve is too large. As suggested in the videos, a remaining angle greater than PI/20 is considered suitable to disregard the integral coefficient.

## **Next session tasks:**
In the next session, I will work on the four cameras we just received, connecting them to the Nvidia Jetson, testing them, and utilizing them collectively to identify objects in all directions. Additionally, I will address absolute odometry; currently, our odometry is relative.

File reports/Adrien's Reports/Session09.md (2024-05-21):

# Session report 8: February 07, 2024

**Session objective:** Address bugs in the odometry algorithm and incorporate PID coefficients.

## Trying to determine PID coefficients
Firstly, after conducting some research, I discovered the Ziegler-Nichols method, which involves incrementing the P coefficient while keeping I and D coefficients at zero until the system becomes unstable. Subsequently, with the P coefficient at the stability limit and the frequency of oscillations at this limit, we can easily determine our P, I, and D coefficients by applying the values from the following table:



With low values of P, the system becomes stable very quickly.

 P = 1

 P = 2

At P=3, the system was noticeably less stable but still exhibited a tendency towards stability.

 P = 3.5

Finally, with P=5.2, my system is approaching the stability limit, as the error tends to oscillate with nearly the same frequency and amplitude.

 P = 5.2

I was then able to measure the frequency of the oscillations from the last graph and, using the Ziegler-Nichols table, determine my P, I, D coefficients

Here are the results with the error after implementing the new PID coefficients:



This result is quite unsatisfactory. Despite achieving a final error close to zero, there is a significant overshoot. I need to verify if I made a mistake in applying the Ziegler-Nichols method or if it is not suitable for our system.

## Improving the rotation calibration
As our rotation calibration wasn't very accurate, Loic created a tool fixed on the robot with a hole at the center of inertia. I used a large wooden panel with a screw to rotate the robot 360° perfectly on itself and recorded the encoder values for each wheel. With this new calibration i was able to perfectly calibrate the robot.



## Problem with fluctuating values from our encoders.
When doing this rotation calibration i had many issues cause i wasn't getting the same values each time for the same rotation. 

## Solution : one unique print at the end
I spent a considerable amount of time troubleshooting this issue, but we were ultimately able to identify the problem. Printing the values read by the encoders at each interruption significantly slowed down the program, leading to inaccurate values that were time-dependent. Instead of printing the number of ticks at each interruption, I implemented a new 'print' command, which displays the number of ticks for each encoder when called. After making this change, I could consistently read coherent values, which remained the same in each experiment.

## Reducing the sampling frequence
As our Arduino operates with digital signals, we need to sample our measurements. Previously, I had chosen a sampling time of 100ms, but for increased precision, I had to reduce down to 10ms this sampling time.

## **Next session tasks:**
Identify the correct PID coefficients and initiate the use of our cameras to detect Aruco tags on the playground.

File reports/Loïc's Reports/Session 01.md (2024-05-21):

# October 14, 2023
## 3D modeling
### Wheel adapter
Based on the wheels we ordered from Amazon, I modeled in 3D and 3D printed an adapter to mount them on the motor shafts, as they are sold as rolleur wheels and are therefore freewheels (mounted with a bearing in the hub) and so we can't use them directly to transmit torque from the motor on which they are individually mounted.

  

To make these wheels suitable for our use, I simply removed the bearings from them and replaced them with a 3D printed (in PETG for reliability) adapter that fits the motor shafts. The wheels are then mounted on the motor shafts. In my original design, the adapter was screwed onto the motor shaft, but I had to modify it to make it press-fit because the hole for the screw (in red on the picture above) was not accessible because the wheel covered it. To make sure to have a tight fit, I 3D printed the adapter without any tolerance and I filed it down just a little bit to make it fit just enought to stay in place without risking to damage the motor shafts.

   

In order to transmit the motor torque, I designed the adapter with a flat surface identical to the one on the motor shaft. Because the wheels are only press-fit on the motor shafts, I will have to keep an eye on them to make sure they don't slip. I will have to solve this issue on the next version of the adapter.

   

> We can see a wheel in black, the 3D-printed adapter in white and a motor mounted on a previously-produced 3D-printed bracket, which in turn is screwed onto the laser-cut plywood frame.

### Motor mount
The motors currently in place are DC motors with a planetary gearbox, but we'd like to try brushless motors to see if they're more efficient than DC motors. The brushless motors we have are much larger in diameter but smaller in length, so I had to redesign the motor mount to accommodate them. I also had to redo the spacers between the plywood panels that form the frame, as the brushless motors are too big to fit between the panels.

 

> Both models can be 3D printed without any support so it reduces post processing, material waste and print time.



> On the left the DC motors, on the right the brushless motors.

## Table
We received the game mat that will be put on the 2*3m table. This mat delimits the different action zones in which the robot must move and perform actions determined by the cup rules.
We unwrapped the mat to make sure everything was in order and to see what it looked like. We thought it would be made in a single piece, but it is actually made in 3 pieces that we will have to assemble. We will have to find a way to make the joints between the pieces as invisible as possible.

     

## Next time
I will modify the motors connectors by 3.5mm bullet connectors so we can plug them to the ESCs we received the same day as the mat. 

After that, I will make a quick Arduino code to test the motors and ESCs to make sure everything works as expected.

Then, I will concentrate at the modification of the futur version 3 of the robot to move the wheels to the middle of the chassis and create a system so the motors remain at the rear of the rolling base.



If I have some time left, I will finish the hardware of the grabber system and make a quick Arduino code to test it.

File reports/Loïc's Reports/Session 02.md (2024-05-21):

# October 21, 2023
## Electronics
The brushless motors we ordered were send with male MT30 connectors which are not convinient for several reasons:
- They are not common so difficult to source at a reasonable price
- They don't allow to swap two phases lines to reverse the rotation direction

Because the ESCs are sold without any connectors, I decided to replace the motors connectors by 3.5mm bullet connectors so we have female connectors on the ESCs and male connectors on the motors. The use of bullet connectors is much more convinient for the reasons mentioned above.

     

Once I finished soldering the connectors, I tested the motors with the ESCs and it worked perfectly. I used a 6S (22V Li-ion) battery to power the ESCs wich are rated for 3S to 6S. I powered the Arduino with the 5V output of the ESC. I mounted the motor on the 3D printed support that will later be used to mount it on the robot.

 

I wrote the following code to test the motors:

```c++
#include <Servo.h>

Servo esc;

int potPin = A0;
int throttle;

void setup() {
  esc.attach(9, 1000, 10000);
}

void loop() {
  throttle = map(analogRead(potPin), 0, 1023, 1000, 10000);
  esc.writeMicroseconds(throttle);
  delay(10);
}
```
My code is really basic, it reads the value of a potentiometer on pin **A0** and writes the value to the ESC using the library ***Servo***. The ESC then sends the corresponding three-phase PWM signal to the motor. The motor speed is proportional to the PWM signal. A video of the test can be found [here](https://github.com/Loic-LEROY/PolyMartian/blob/main/Lo%C3%AFc's%20Reports/src/session_02/run%20test.mp4) on the GitHub repository.

I was really impressed by quality of the motors, they run super smooth and are really quiet.

Here is the whole test setup:



## 3D Modeling
Based on the latest rules given by the cup administrators, we decided to change our strategy. Instead of storing the plants into the robot, we will push all of them in the same time. This way, we don't have to manipulate the plants one by one to put them in the robot. We will directly push them with the robot frame. This will conciderably reduce the time spend to collect the plants.

To match this new strategy, I modeled on SolidWorks a whole new robot. The motorisation remains the same, we still have a grabber to place the plants in the planters. Here is a comparison of the very first version and my first model of the new version:

  

> On the left le first version of the robot, on the right the new version

Before building the new robot, I already found that there is a problem with the new design. The wheels are at an extremity of the robot, so it reduces the maniability of the robot by augmenting the truning radius. To solve this issue, I will have to move the wheels closer to the center of the robot like on the first version. The problem now is that I cannot move the motors from their position because they would block the area where the plants are "stored". The solution is to let the motors where they are and to move the wheels closer to the center of the robot. This will require to use a belt transmission to connect the motors to the wheels. I will also had a belt tensioner to be able to adjust the belt tension.

Here is the new version I come up with:



> Some parts are transparent for a better visibility but they won't be transparent on the real robot.

As you can see on the image above and the images below, I also added one freewheel to each side of the robot. These wheels are not motorised, they aim to measure the distance travelled by the robot. This will allow us to know the position of the robot on the field. I will use a rotary encoder to measure the rotation of these wheels. By measuring the position of the robot on non driving wheels, we ensure that the position is not affected by the slippage of the driving wheels which can append when the robot accelerates or decelerates too much or if it loses traction due to the ground conditions like grease or dust.

   

> Some details of the mounting of the freewheels and the driving wheels.

In order to ensure a good regidity off the mounting of the driving wheels, I added a 3D printed part with a triangular shape for resistance and it creates a great pivot for the driving wheels. More over, I've modelled a system that maintains pressure on the freewheels to avoid distorting the measurements should they come off the ground due to imperfections in the playing surface. This system consists of a swinging arm to which the freewheel is pivotally attached, and which is pressed towards the ground by a spring that forces it to lower the freewheel.

For information, the spring and its support are not yet modeled on the robot model. It will be done next time; all pivot are ball-bearing mounted to reduce friction. All features from the previous version have not been added yet.

## Next time
- Finish the freewhell system
- Model the belt tensioner
- Add the previous features (already modeled for the previous version)

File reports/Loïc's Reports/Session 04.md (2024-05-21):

# December 12, 2023
## 3D Modeling
During this session, I modeled on SolidWorks the belt tensioner. To tension the belt, I made oblong holes in the panels of the robot's frame so the motor mounts can translate and by controlling the center to center distance between the two pulleys, I can adjust the tension of the belt.

 

> Belt tensioner

Since I mouved the wheels to the center of the robot, they are no longuer directly mounted on the motor shaft so I had to redesign the hub adapter because the motor's shaft are 8mm in diameter and the wheel's axis only 5mm. Moreover, I would like to transmit the torque from the pulley to the wheel.
I came up with the following design which aims to be pressed into the wheel and goes arround the pulley. Then a screw can be added to avoid a rotation between the wheel and the pulley.



> New wheel hub

To finish, I modeled the encoders mount. I modified the previously made pivot arm which hold the freewheel so the encoder can be mounted on it. The encoders are take from the motor. So I modeled the piece in order to ba able to reuse the encoder's screws.

 

> Encoder mount, the encoder is the green part

## 3D Printing
During the session, I printed the belt tensioner and the wheel hub. I also printed the encoder mount. All pieces are perfect. I chose to print them in PETG because it is stronger than PLA and easy to print.

## Hand Made
I spent a large part of the session to make some holes in the frame of the robot. I forgot a few holes for some screw so I had to make them. It was not difficult because I took the time to take the measures and to mark the holes before drilling them. I also mounted the ball freewheel, the new mounts. I put all the ball bearings into the different parts and the brass inserts as well.

     

> Some photos of the robot from different angles. Plastic protections had not been removed yet. Some screws are missing to save time.

## Next Session
- Cut and thread the shafts
- Finish the frame
- Mount the freewheels (coding wheels)
- Mount the grabber

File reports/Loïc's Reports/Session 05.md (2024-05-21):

# January 08, 2024
## Hand made
### Belts
During this session, I sewed the belts for the motorized wheels. The wire provides good tensile strength and the glue prevents the wire from loosening. I used a glue which remains soft after it dries so the assembly stays flexible.

  
> An assembled belt

### Motors mounting holes
After I finished making the two needed belts, I modified the robot frame to make the motors mounting holes oblong. This allows the motors to glide along the frame and adjust the belts tension. Then, I mounted the motors and the wheels with the belts to check if everything was working properly.

 

> A 3D view of the oblong holes I made on the real frame.

### Wheels' shafts
During the last part of the session, I cutted the wheels' shafts to the right length and I tried to thread them but it didn't work because the die was damaged. I planned to thread the ends and then use nuts to stop the shafts axially. I will have to find a new die to finish this task or find another way to stop the shafts.

## Next session
- Solve the shafts problem
- Reassemble the robot entirely
- Add the vertical gripper I made previously
- Add the coding wheels I made previously

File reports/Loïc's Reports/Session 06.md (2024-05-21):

# January 16, 2024
### Robot assembly
During this session, finished to assemble the rolling base. It is now ready to be programmed and tested. The next step is to assemble the gripper. We also need to find a way to power the robot. We will probably use a battery pack. For the moment, I am using my home made portable power supply but it is not very convenient and it does not last a long time. I also assembled the coding wheels and the motor encoders. I adjusted the height of the yellow plastic parts to make sure the wheels are touching the ground and that the robot is stable.

  

> The rolling base with my portable power supply on top; a coding wheel mounted onto the rolling base.

### Mecanical power transmission
In order to transmit the power from the motors to the wheels, I chose to use a belts. Last session, I tried to make them myself by sewing the ends of a belt together. During this session, I performed a stress test on the belts by running the motors and pushing the robot against the floor. The belts broke after a few seconds. I then decided to buy some belts online. I found some that are the right size. I will receive them in a few days. I think the problem was the wire I used to sew the ends together. It was too thin and made out of cotton and it broke. Maybe if I had used a thicker wire made out of a stronger material like nylon, it would have worked.



> The belts I bought online.

While testing the belts, I noticed that the belts did not slip on the pulley so I conclued that the system to tension the belts is valid.

## Next session
- Solve the shafts problem
- Add the vertical gripper I made previously

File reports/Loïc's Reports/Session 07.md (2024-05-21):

# January 23, 2024
## 3D modeling
### Vertical rail mounting
In order to mount the vertical rails, I modeled on SolidWorks two pieces which will hold the rails in place. The first one avoid the rails to move vertically by blocking it at the bottom. It also blocks all the horyzontal translations. The piece is screwed to the base of the robot. The second piece blocks the rails from the rear and blocks the vertical translations thanks to a through screw. It is screwed to the top panel of the robot's frame. The two pieces are shown below in orange.

   

> The two pieces are shown in orange

## 3D printing
### Vertical rail mounting
I printed the two pieces in PETG with a 0.2mm layer height and 50% infill. This settings are the best compromise between printing time and strength. The pieces are shown below in PrusaSlicer.



> The two pieces after slicing

 

> The two pieces after printing

## Laser cutting
### Panels' frame
Since we switched to the U-shaped frame, we made a lot of holes modifiactions. In order to keep our work clean, we decided to laser cut a new frame which includes all the holes we made after the first laser cut. Once the frame was cut, I assembled the robot with the new frame. The frame is shown below.

  

> The new frame and the robot reassembled

### Coding wheels
Last session, I assembled the coding wheels but the springs supposed to keep the wheels in contact with the ground were too strong and their supports were too weak. I made some new ones and I cutted the springs in half in order to reduce their strength.

 

> The new springs and their supports in blue printed plastic

## Next session
- Add to the robot the stepper motor to move the vertical rails.
- Design a grabber that can grab several plants at once.

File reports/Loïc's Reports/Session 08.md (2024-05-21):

# February 07, 2024
### Vertical rail
Last session, I mounted the vertical rail onto the robot but they looked a bit fragile. I decided reprint them with a thicker wall so they are more robust. Now the vertical rail is strongly attached to the robot, I can fix the stepper motor and the pulley on it. The stepper motor I chose is a pancake Nema 17. It is the same motor as a classic Nema 17 but it is twice as thin and twice as light. The classic version has a torque of **0.26 Nm** but the pancake version has a torque of **0.16 Nm** yet it is enough for the vertical rail which is not supposed to carry a heavy load (a few tens of grams).



> Left: pancake Nema 17; Right: classic Nema 17

 

> The stepper motor is fixed on top of the vertical rail, the pulley is fixed at the bottom of the rail. The belt is around the pulley and the motor shaft and is fixed to the cart of the rail.

### Belt mount
In order to move the cart up and down, a belt is attached to it and turns around the stepper on top of the rail and a pulley at the bottom of the rail. The belt is a GT2 belt, it is a standard belt for 3D printers and CNC machines. The belt is fixed to the cart with a 3D printed part. The part is designed to be fixed to the cart with 4 screws and to hold the belt with 4 other screws which go through the part and the belt. This way, the belt is strongly attached to the cart and the part is strongly attached to the cart.



## 3D modeling
### Ladybug
Now the main robot is almost physically complete, I started to model the ladybugs. These mini robots are designed to pollinate plants picked up within the first 100 seconds by the main robot. To validate this action, every ladybug must move from the departure base to a plant placement area and touch one of the plants.

For the modeling, I used the same process as for the main robot. I started by listing the items a ladybug should carry :
- A lidar or a ultrasonic sensor (to detect the obstacles)
- A Raspberry Pi zero W (Wifi version)
- 2 motors (a DC motor for the motor wheels and a servo motor for the dircetion wheel)
- A battery (Lipo 3.7V 500mAh for its lightness and its small size)
- ...

Then I found on the internet the models of the Raspberry Pi zero and the lidar because they are standard items and it would be a waste of time to model them myself. I have an idea of the size of the motors and the battery we are going to use, so I modeled them myself. Now I have all the models of the main componants, I can start to design the chassis of the ladybug.



> First draft of the ladybug. Ultra compact and light.

## Next session
- Mount the new wheels on the main robot
- Update the grabber's design to fit the vertical rail's belt mount
- Design the main robot's horyzontal rails
- Mount them on the robot
- Model the ladybug's chassis

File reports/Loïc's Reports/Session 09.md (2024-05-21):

# February 14, 2024
## Grabber
During this session, I modeled, 3d printed, and assembled the grabber. One to tilt the gripper forward and one to open and close the gripper hooks. I use servos because they are very easy to command and very compact compared to their strength. The part that holds the grabber is also used to secure the rail belt. Thera are four screws that go through the belt in order to pinch it so it can not glide off the part.

 

> The upgraded grabber

## Wheels
After a few tests, we found up that the wheels we were using on the robot were not straight at all (buckling of approx. 3 mm) so we ordered some new ones made out of aluminum and rubber arround. After mounting then, I observed that they are almost perfect. Unfortunatelly the wheels are finner than the old one so we have to put two of them in parallel to get the same width.

 

> The new wheels

## Calibration
In order to calibrate the robot's encoder wheels, I modeled in SolidWorks and then laser-cut a plate to fix the robot's center of inertia at a fixed point. This enables the robot to be rotated around a perfectly fixed axis of rotation, and the number of steps taken by each encoder wheel to be counted, so as to check whether or not they are identical, or even to determine a coefficient of divergence between the two. The part is screwed to the robot at both ends, and screwed to a panel on which the robot rolls.



> The robot on the test bench. The part I've added is the light wood part in the middle of the robot.

## Next session
- Design, print and mount the horyzontal rails on the robot.
- Continued progress on ladybug design

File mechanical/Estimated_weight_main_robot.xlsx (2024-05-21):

Componant | Min Weight (g) | Max Weight (g) | Details
2 motors | 1000 | 2000
2 wheels + ball freewheel | 130 | 200
Nvidia Jetson | 240 | 240
4 aluminium profiles 300mm | 560 | 560
2 stepper motors Nema17 | 560 | 560
Threaded rod (clamp) | 20 | 20
Servomotor (clamp) | 20 | 20
2 Lipo Batteries | 600 | 1000
Stop emergency button | 50 | 50
300mm linear guide rail (clamp) | 270 | 270
3 cameras | 90 | 240 | 30 grams for a raspberry pi camera | 80 grams for "Je vois Pro" camera
2 Cytron electronic boards | 45 | 45
Total | 3585 | 5205

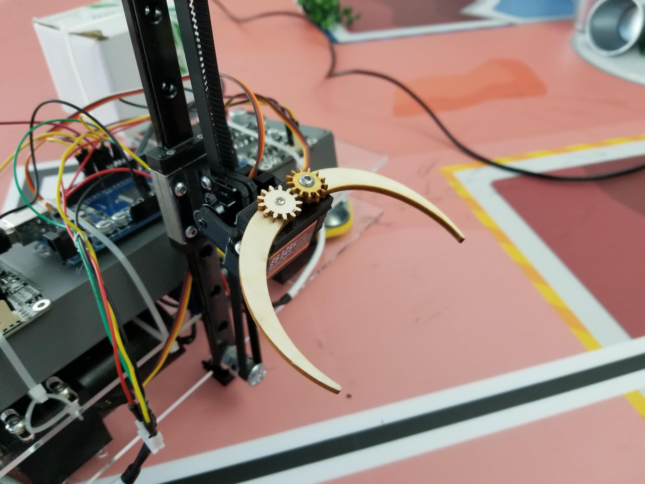
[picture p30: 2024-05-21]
reports/Loïc's Reports/src/session_09/grabber3.jpeg

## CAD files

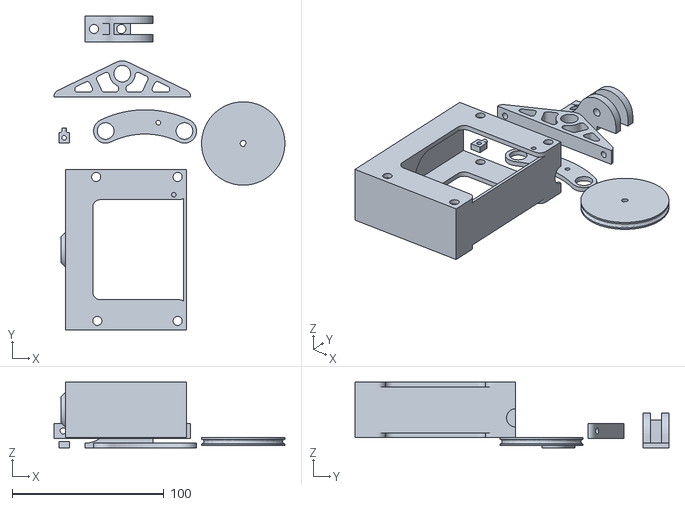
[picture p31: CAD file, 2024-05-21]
reports/Loïc's Reports/src/session_03/support pivot.stl
152.3 x 207.2 x 43.2

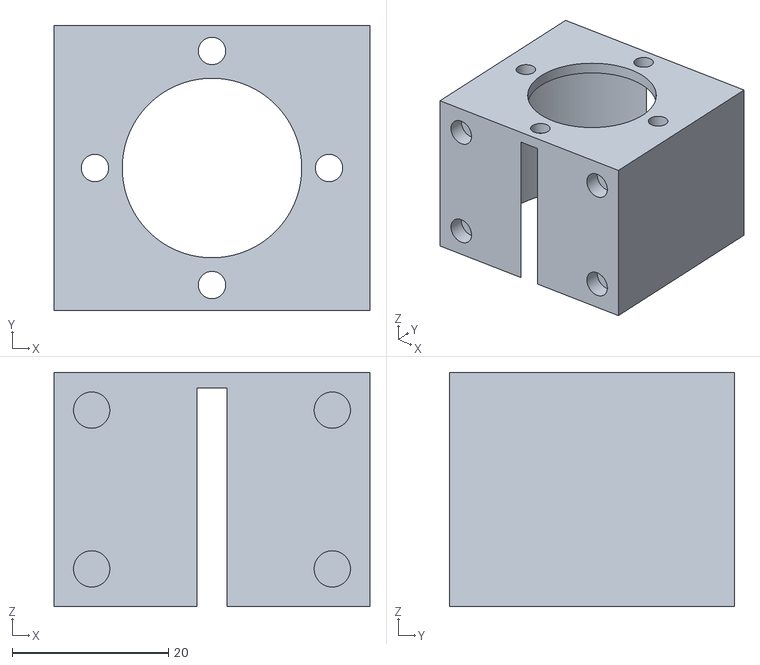
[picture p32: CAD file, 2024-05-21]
reports/Loïc's Reports/src/session_04/support moteur + tendeur.STL
40.5 x 36.5 x 30.0

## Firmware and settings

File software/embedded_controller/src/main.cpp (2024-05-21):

#include <Arduino.h>
#include <String.h>

hw_timer_t * timer = NULL;

// MOTORS
#define L_MOTOR 18            // left motor
#define L_MOTOR_DIRECTION 5 // rotation direction of left motor
#define R_MOTOR 34            // right motor
#define R_MOTOR_DIRECTION 35  // rotation direction of right motor

//ENCODERS
#define L_ENCODER_A 2   // left encoder
#define L_ENCODER_B 15 
#define R_ENCODER_A 27  // right encoder
#define R_ENCODER_B 26

#define L_ticks_per_mm 5.492  // number of ticks (points) read by the left encoder per mm travelled
#define R_ticks_per_mm 5.505 // same for right encoder

// Trigonometric direction rotation
#define L_ticks_per_rad 950.79 //  number of ticks (points) read by the left encoder processing a 1 radian rotation in trigo direction
#define R_ticks_per_rad 914.35 // by the right encoder

long L_encoder_ticks = 0;
long L_encoder_previous_ticks = 0;
long L_encoder_deltaTicks = 0;    // number of ticks measured by the left encoder after a short time

long R_encoder_ticks = 0;
long R_encoder_previous_ticks = 0;
long R_encoder_deltaTicks = 0;    // number of ticks measured by the right encoder after a short time

float distance_travelled_ticks = 0;  // distance in mm travelled by the robot after a short time
float angle_travelled_ticks = 0;    // angle travelled by the robot in ticks

float integral_error_distance_term = 0;
float integral_error_angle_term = 0;

float error_angle = 0;

float L_command;
float R_command;
float previous_L_command;
float previous_R_command;

int distance_setpoint_mm;
float distance_setpoint_ticks;
float distance_command_ticks;
float previous_distance_command_ticks;

int distance_then_rotation_setpoint_ticks[2];

float angle_setpoint_rad;
float angle_command_ticks;
float previous_angle_command_ticks;

int sample_time = 100;


// Maximum and minimum motors' speed allowed and max acceleration
const int MAX_SPEED = 75; // in ticks/sampletime
const int MAX_ACCELERATION = 5;
const int MAX_DECELERATION = 5;

float new_coef_deceleration;


bool closed_loop = true; // if true we apply a PID

// PID coefficients
// For distance
float P_V = 1;    // proportional coefficient
float I_V = 0.0;  // integrating coefficient
float D_V = 0.0;  // derivative coefficient

// For rotation

float P_W = 0.5;  // proportional coefficient
float I_W = 0.3;  ;  // integrating coefficient
float D_W = 0.0;  // derivative coefficient

float X_real = 0;
float Y_real = 0;
float Z_real = 0;
float V_real = 0;
float W_real = 0; // angular speed

int X_target = 0;
int Y_target = 0;
int Z_target = 0;

float X_theoretical;
float Y_theoretical;
float Z_theoretical;
float V_theoretical;
float W_theoretical;

float error_XY;
float error_Z;
float error_V;
float error_W;

int pid_v;
int pid_w;

unsigned long previousmillis = 0;  // Last measured time

char command[14];  // Store character by character the sent command with serial connection
int position_character = 0;

bool robot_moving = false;  // Indicate if a command has been sent
bool antiwindup = false;

float current_speed = 0;
float speed_target = 0;
float previous_speed_target = 0;
float left_speed_target;
float right_speed_target;
float left_speed_coef;
float right_speed_coef;

float acceleration_time;
float acceleration_distance;
float deceleration_time;
float deceleration_distance;
int constantspeed_time; // is int
float constantspeed_distance;
float maxspeed_reached;

enum Phase {STATIONARY, ACCELERATION, CONSTANT_SPEED, DECELERATION};

enum Trajectory {FORWARD_LINEAR, BACKWARD_LINEAR, LEFT_PIVOT, RIGHT_PIVOT};

int to_coordinates_trajectory = 0;

bool coordinates_target = false;

Trajectory trajectory_type = FORWARD_LINEAR;

Phase speed_phase = STATIONARY;

int target_ticks;

void setup() {
  //MOTORS
  pinMode(L_MOTOR, OUTPUT);
  pinMode(L_MOTOR_DIRECTION, OUTPUT);
  pinMode(R_MOTOR, OUTPUT);
  pinMode(R_MOTOR_DIRECTION, OUTPUT);

  //ENCODERS
  pinMode(L_ENCODER_A, INPUT_PULLUP);  // INPUT_PULLUP so if there is no signal on this pin, we will receive the value 1, so when we will reveive something it will be 0
  pinMode(L_ENCODER_B, INPUT_PULLUP);
  pinMode(R_ENCODER_A, INPUT_PULLUP);
  pinMode(R_ENCODER_B, INPUT_PULLUP);

  // ENCODERS Interruptions
  // The macro CHANGE triggers an interrupt when the pin changes, whether from LOW to HIGH or HIGH to LOW
  attachInterrupt(digitalPinToInterrupt(L_ENCODER_A), L_Encoder_interrupt, CHANGE);
  attachInterrupt(digitalPinToInterrupt(R_ENCODER_A), R_Encoder_interrupt, CHANGE);

  //SERIAL COMMUNICATION
  Serial.begin(115200);  // speed of communication

  // Our integration and derivation in PID are done every sample_time seconds
  I_V = I_V * sample_time; // cause the integral coefficient is applied for each sample_time seconds. Indeed we integrate error*dt
  D_V = D_V / sample_time; // we derivate derror/dt 
  
  // TODO : replace millis with a timer !! 
  //uint8_t timer_id = 0; // Defines which timer will be used on the ESP32
  //uint16_t prescaler = 80; // Between 0 and 65 535 (timer division factor)
  //int threshold = 1000000; // 64 bits value (limited to int size of 32bits)

  //timer = timerBegin(timer_id, prescaler, true);
  //timerAttachInterrupt(timer, &timer_isr, true);
  //timerAlarmWrite(timer, threshold, true); // A timer is triggered when threshold is reached
  //timerAlarmEnable(timer);
}

float mm_to_ticks(float distance_mm){
  return distance_mm*(L_ticks_per_mm + R_ticks_per_mm)/2;
}

float ticks_to_mm(float distance_ticks){
  return distance_ticks / ((L_ticks_per_mm + R_ticks_per_mm)/2);
}

float rad_to_ticks(float angle_rad){
  return angle_rad * ((L_ticks_per_rad + R_ticks_per_rad)/2);
}

void motors_command(float L_command, float R_command) {  // L_command and R_command between -255 and 255 (if negative the wheel goes backward)
  if (L_command >= 0) {
    digitalWrite(L_MOTOR_DIRECTION, HIGH);
  } else {
    digitalWrite(L_MOTOR_DIRECTION, LOW);
  }
  if (R_command >= 0) {
    digitalWrite(R_MOTOR_DIRECTION, LOW);
  } else {
    digitalWrite(R_MOTOR_DIRECTION, HIGH);
  }
  analogWrite(L_MOTOR, abs(L_command));
  analogWrite(R_MOTOR, abs(R_command));
}

void L_Encoder_interrupt() {  // called when there is an interruption on the left encoder pin A

  // L_ENCODER_A and L_ENCODER_B are the same signal but are out of phase. We defined the interruption on the L_ENCODER_A pin
  if (digitalRead(L_ENCODER_A) == digitalRead(L_ENCODER_B)) {
    // So if the previous condition is true, it means that when the pin L_ENCODER_A detected a high value and interrupted the programm, the B pin was already detecting a high value
    // So the first signal to have a high value was the L_ENCODER_B, with our configuration it means the wheel is moving forward.
    L_encoder_ticks++;
  } else {  // else the wheel is moving backward
    L_encoder_ticks--;
  }

}

void R_Encoder_interrupt() {  // called when there is an interruption on one of the right encoder pin

  // same explanation as left interrupt function
  if (digitalRead(R_ENCODER_A) == digitalRead(R_ENCODER_B)) {  // the wheel is moving forward
    R_encoder_ticks++;
  } else {  // the wheel is moving backward
    R_encoder_ticks--;
  }
}

void readCommand(){
  if (Serial.available() > 0) {  // Si on a envoyé un charactère
    if (position_character == 0) {
      for(int i=0; i<5; i++){
        command[i] = 0;
      }
    }

    char character = Serial.read();

    if (character == '\n' || character == '\r') {  // Si on envoie la commande via le moniteur série en tappant entrée
      position_character = 0;                      // alors on remet à 0 l'indice auquel on ajouter le prochain caractère pour la prochaine commande
      integral_error_angle_term = 0;
      integral_error_distance_term = 0;

      parseCommand(command);
      return;
    }
    command[position_character++] = character;
  }
}

void parseCommand(char command[]) {
  // Analyze the String command to retrieve its parameter values.
  String commandString(command);

  if (commandString.startsWith("d=")) {  // Checks if the command starts with "d=" to indicate we want to send a distance
    // Extracts the substring next to the "=" sign
    String distanceSubString = commandString.substring(2);
    // Converts it to an int and defined it as the distance command
    distance_setpoint_mm = distanceSubString.toFloat();
    if (distance_setpoint_mm>=0){
      trajectory_type = FORWARD_LINEAR;
    }
    else{
      trajectory_type = BACKWARD_LINEAR;
    }
    distance_command_ticks = mm_to_ticks(distance_setpoint_mm);
    distance_setpoint_ticks = abs(distance_command_ticks);
    trajectory_order();
  }

  else if (commandString.startsWith("r=")) {  // Checks if the command starts with "r=" to indicate we want to send an angle in degree
    // Extracts the substring next to the "=" sign
    String angleSubString = commandString.substring(2);
    // Converts it to radians and defined it as the angle command
    angle_setpoint_rad = (angleSubString.toFloat() * PI) / 180;
    if (angle_setpoint_rad>=0){
      trajectory_type = LEFT_PIVOT;
    }
    else{
      trajectory_type = RIGHT_PIVOT;
    }
    distance_command_ticks = rad_to_ticks(angle_setpoint_rad);
    distance_setpoint_ticks = abs(distance_command_ticks);
    trajectory_order();
  }

  // Assign coordinates to the current location
  else if(commandString.startsWith("p=")) { // Checks if the command starts with "p=" to indicate we want to redefine the absolute position of the robot. Format: p=xxxx:yyyy:zzzz in millimeters
    // Extracts the substring next to the "=" sign
    X_real = commandString.substring(2, 6).toInt();
    Y_real = commandString.substring(7, 10).toInt();
    Z_real = commandString.substring(11, 14).toInt();
  }

  // Assign coordinates to the current location
  else if(commandString.startsWith("go=")) { // Checks if the command starts with "go=" to indicate we want to redefine the absolute position of the robot. Format: go=xxxx:yyyy:zzzz
    // Extracts the substring next to the "=" sign
    X_target = commandString.substring(3, 7).toInt();
    Y_target = commandString.substring(8, 12).toInt();
    Z_target = commandString.substring(13, 17).toInt();
    float X_distance = mm_to_ticks(X_target)-X_real;
    float Y_distance = mm_to_ticks(Y_target)-Y_real;
    distance_command_ticks = sqrt( X_distance*X_distance + Y_distance*Y_distance );
    distance_then_rotation_setpoint_ticks[1] = distance_command_ticks;
    Z_target = (Z_target*PI) / 180;
    distance_then_rotation_setpoint_ticks[0] = rad_to_ticks(Z_target) - Z_real;
    coordinates_target = true;
    trajectory_order();
  }

  else if(commandString.startsWith("P_V=")){
    P_V = commandString.substring(2).toFloat();
  }

  else if(commandString.startsWith("I_V=")){
    I_V = commandString.substring(2).toFloat() * sample_time;
  }

  else if(commandString.startsWith("D_V=")){
    D_V = commandString.substring(2).toFloat() / sample_time;
  }

  else if(commandString.startsWith("PR=")){
    P_W = commandString.substring(2).toFloat();
  }

  else if(commandString.startsWith("IR=")){
    I_W = commandString.substring(2).toFloat() * sample_time;
  }

  else if(commandString.startsWith("DR=")){
    D_W = commandString.substring(2).toFloat() / sample_time;
  }

  else if(commandString.startsWith("sampling=")){
    float new_sample_time = commandString.substring(2).toFloat();
    float ratio =  new_sample_time / sample_time;
    I_V *= ratio;
    D_V /= ratio;
    sample_time = new_sample_time;
  }

  else if(commandString.startsWith("x=")) { // Checks of the command starts with "x=" to indicate we want to define the absolute position in x of the robot.
    X_real = commandString.substring(2,5).toInt();
  }

  else if(commandString.startsWith("y=")) { 
    Y_real = commandString.substring(2,5).toInt();
  }

  else if(commandString.startsWith("z=")) { 
    Z_real = commandString.substring(2,5).toInt();
  }

  else if (commandString.startsWith("stop")) {  //
    motors_command(0, 0);
  }

  else if (commandString.startsWith("print")){
    Serial.println(L_encoder_ticks);
    Serial.println(R_encoder_ticks);

    Serial.print(X_theoretical);
    Serial.print(":");
    Serial.print(Y_theoretical);
    Serial.print(":");
    Serial.println(Z_theoretical);

    Serial.print(X_real);
    Serial.print(":");
    Serial.print(Y_real);
    Serial.print(":");
    Serial.println(Z_real);

    Serial.println("distance and angle commands");
    
    Serial.print("distance command mm = ");
    Serial.println(distance_command_ticks);
    Serial.print("angle command rad = ");
    Serial.println(angle_command_ticks*180/PI);
  }

  else if (commandString.startsWith("reset")) {  // Useful when the robot wedges itself against a border to calibrate.
    distance_command_ticks = 0; // We reset the commands 
    angle_command_ticks = 0;
    L_encoder_ticks = 0;  // We reset the count of encoders ticks to 0.
    R_encoder_ticks = 0;
  }
}

void trajectory_order(){
  if (coordinates_target){
    distance_command_ticks = distance_then_rotation_setpoint_ticks[to_coordinates_trajectory];
    distance_setpoint_ticks = abs(distance_command_ticks);
    if (to_coordinates_trajectory==0){
      trajectory_type = LEFT_PIVOT;
      to_coordinates_trajectory++;
    }
    else{
      trajectory_type = FORWARD_LINEAR;
      to_coordinates_trajectory = 0;
      coordinates_target = false;
    }
  }
  speed_phase = ACCELERATION;
  get_phases_distances();
}

void get_phases_distances(){
  // used to determine acceleration distance and deceleration distance
  acceleration_time = floor(MAX_SPEED / MAX_ACCELERATION);
  acceleration_distance = (MAX_ACCELERATION * acceleration_time * acceleration_time)/2; // kinematic equation for uniformly accelerated motion : Displacement=InitialPosition+ 1/2 ×Acceleration×(Time)² 
  deceleration_time = floor(MAX_SPEED / MAX_DECELERATION);
  deceleration_distance = (MAX_DECELERATION * deceleration_time * deceleration_time)/2;
  
  if (acceleration_distance + deceleration_distance > distance_setpoint_ticks){ // Triangle speed profile, we don't have the time to have a constant speed phase
    constantspeed_distance = 0;
    constantspeed_time = 0;
    deceleration_time = floor(sqrtf( (2*distance_setpoint_ticks*MAX_ACCELERATION) / ( (MAX_DECELERATION)*(MAX_ACCELERATION+MAX_DECELERATION) ) )); 
    deceleration_distance = (MAX_DECELERATION * deceleration_time * deceleration_time)/2;
    acceleration_distance = distance_setpoint_ticks - deceleration_distance;
    maxspeed_reached = deceleration_time * MAX_DECELERATION;
  }
  else{
    maxspeed_reached = MAX_SPEED;
    constantspeed_distance = distance_setpoint_ticks - acceleration_distance - deceleration_distance;
    constantspeed_time =  floor(constantspeed_distance / maxspeed_reached) ;
  }

  // Now we adjust the deceleration coefficient to modify the deceleration slope (as we can't be more precise when calculating deceleration time due to roundings)

  // The formula for Uniformly accelerated rectilinear motion is accceleration= vf²-vi² / 2(xf-xi), f means final, i means initial.
  // here vf = 0, so accceleration= -vi² / 2(xf-xi), we don't consider the minus sign as we are searching for the absolute value of the coefficient (like MAX_DECELERATION which was positive)
  // xf is the final position and xi the position at the beginning of deceleration phase so xf - xi = deceleration_distance
  new_coef_deceleration = maxspeed_reached*maxspeed_reached / (2 * (distance_setpoint_ticks - maxspeed_reached * constantspeed_time - acceleration_distance));
  deceleration_time = ceil(maxspeed_reached/new_coef_deceleration); // ceil() cause it's better to have a greater slope than going beyond the value
  deceleration_distance = (new_coef_deceleration*deceleration_time*deceleration_time)/2; //
  
}

void get_speed_target(){
  previous_speed_target = speed_target;
  target_ticks++;
  if (speed_phase==ACCELERATION){
    if ( target_ticks >= acceleration_time){

      if (constantspeed_time==0){
        speed_phase = DECELERATION;
      }
      else{
        speed_phase = CONSTANT_SPEED;
        
      }
      target_ticks = 0;
    }
    else{
      speed_target += MAX_ACCELERATION;
    }
  }
  else if (speed_phase==CONSTANT_SPEED){
    if ( target_ticks >= constantspeed_time){
      speed_phase = DECELERATION;
      target_ticks = 0;
    }

  }
  else if (speed_phase==DECELERATION){
    if ( target_ticks >= deceleration_time){
      speed_target = 0;
      speed_phase = STATIONARY;
      target_ticks = 0;
      V_theoretical = 0;
      W_theoretical = 0;

      if (coordinates_target){
        trajectory_order();
      }
    }
    else{
      speed_target -= new_coef_deceleration; //We substract the adjusted new coefficient not the maximal one
    }
  }

  switch(trajectory_type){
    case BACKWARD_LINEAR:
      left_speed_coef = -1;
      right_speed_coef = -1;
      break;
    case LEFT_PIVOT:
      left_speed_coef = -1;
      right_speed_coef = 1;
      break;
    case RIGHT_PIVOT:
      left_speed_coef = 1;
      right_speed_coef = -1;
      break;
    default:
      left_speed_coef = 1;
      right_speed_coef = 1;
      break;
  }

  left_speed_target = speed_target * left_speed_coef;
  right_speed_target = speed_target * right_speed_coef;
}

void get_theoretical_speed_and_position(){
  get_speed_target();
  V_theoretical = left_speed_target + right_speed_target; // we don't divide by two cause we compare angles so it will be useless to do the same operation on the two compared quantities to evaluate the difference
  W_theoretical = right_speed_target - left_speed_target;
  
  Z_theoretical += W_theoretical; // différence de vitesse
  X_theoretical += V_theoretical * cos(Z_theoretical);
  Y_theoretical += V_theoretical * sin(Z_theoretical);
}

void get_real_speed_and_position(){
  V_real = distance_travelled_ticks;
  W_real = angle_travelled_ticks;
  Z_real += W_real;
  X_real += V_real * cos(Z_real); 
  Y_real += V_real * sin(Z_real); 
}

void get_errors(){
  get_theoretical_speed_and_position();
  get_real_speed_and_position();
  float error_distance = sqrt( pow(X_theoretical - X_real, 2) + pow(Y_theoretical - Y_real,2));
  float error_angle = 0;
  if (X_theoretical != X_real || Y_theoretical!=Y_real){
    error_angle = atan2(Y_theoretical - Y_real, X_theoretical - X_real) - Z_real;
  }
  error_XY = error_distance * cos(error_angle);
  error_V = V_theoretical - V_real;
  
  error_Z = Z_theoretical - Z_real;
  error_W = W_theoretical - W_real;
}

void correct_distance() {
  get_errors();

  if (antiwindup){ // then we only apply a proportional correction
    pid_v = (int)(P_V * error_V);
    pid_w = (int) (P_W * error_W);
  }
  else{
    pid_v = (int) (P_V * error_V +  I_V * error_XY  ); //  + D_V*(speed_target-previous_speed_target)
    pid_w = (int) (P_W * error_W +  I_W * error_Z  );
  }
  
  L_command = pid_v - pid_w;
  R_command = pid_v + pid_w;

  previous_L_command = L_command;
  previous_R_command = R_command;

  motors_command(L_command, R_command);  // we send the command to the motors
}

void loop() {

  readCommand(); // vérifier qu'on est pas bloqué, ajout de buzzer, timer

  if (millis() - previousmillis > sample_time) {  // we measure the number of ticks every sample_time milliseconds while et read command 
    previousmillis = millis();
  
    L_encoder_deltaTicks = (float)L_encoder_ticks - L_encoder_previous_ticks; // éviter les interruptions pendant le calcul.
    R_encoder_deltaTicks = (float)R_encoder_ticks - R_encoder_previous_ticks; // si while(temps>sample_time) 
    L_encoder_previous_ticks = L_encoder_ticks;
    R_encoder_previous_ticks = R_encoder_ticks;


    distance_travelled_ticks = (L_encoder_deltaTicks + R_encoder_deltaTicks);  // Distance travelled = average of distance travelled by each coding wheel or not divided by two if compared with theoretical
    current_speed = ticks_to_mm(distance_travelled_ticks) / (sample_time * 0.001); // in mm per sec

    angle_travelled_ticks = R_encoder_deltaTicks - L_encoder_deltaTicks; // we don't divide by two cause compared with theoretical angle which is not divided by two

    previous_distance_command_ticks = distance_command_ticks;
    previous_angle_command_ticks = angle_command_ticks;
    distance_command_ticks -= distance_travelled_ticks;  // Remaining distance to achieve (error)
    angle_command_ticks -= angle_travelled_ticks;      // Remaining angle to achieve (error)

    String commandString(command);
    if ( (commandString.startsWith("d=") || commandString.startsWith("r=") || commandString.startsWith("go=")) && closed_loop) {
      correct_distance();
    }

  }
}

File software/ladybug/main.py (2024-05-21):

import DWM1001
import RobotController
import machine
import gyro
import math
import Point
import utime
import random
import Switch
import Zone
import PlantPositionGetter

isBlue = False
isYellow = True

yellowMiddleZone = Zone.Zone(xLow = 0.000,
                             xHigh = 0.450,
                             yLow = 1.250,
                             yHigh = 1.725)

blueMiddleZone = Zone.Zone(xLow=2.550,
                           xHigh=3.000,
                           yLow = 1.250,
                           yHigh = 1.725)

blueBottomZone = Zone.Zone(xLow = 0.000,
                           xHigh = 0.450,
                           yLow = 0.000,
                           yHigh = 0.450)

yellowBottomZone = Zone.Zone(xLow = 2.550,
                             xHigh = 3.000,
                             yLow = 0.000,
                             yHigh = 0.450)

yellowProtectedZone = Zone.Zone(xLow = 2.550,
                                xHigh = 3.000,
                                yLow = 1.550,
                                yHigh = 2.000)

blueProtectedZone = Zone.Zone(xLow = 0.000,
                              xHigh = 0.450,
                              yLow = 1.550,
                              yHigh = 2.000)


switch = Switch.Switch()
dt = 0.1 #s
x0 = 1.500 #m
y0 = 2.000 #m

uart = machine.UART(0,
                    baudrate=115200,
                    tx=machine.Pin(0),
                    rx=machine.Pin(1)
                    )
tag = DWM1001.DWM1001(x0,y0)
middlePointYellowMiddleZone = yellowMiddleZone.getMiddlePoint()

"""zonePoint = Point.Point(x=0.90,
                        y=0.30,
                        radius=0.10)"""
zonePoint = middlePointYellowMiddleZone
"""
xLow = 0
yLow = 0
xHigh = 0.90
yHigh = 0.90
zonePoints = [Point.Point(xLow,yLow),
              Point.Point(xLow, yLow),
              Point.Point(xHigh,yLow),
              Point.Point(xHigh, yHigh)]
"""
robot = RobotController.RobotController(x0, y0)
gyroscope = gyro.Gyroscope()
robot.setCurrentOrientation(-math.pi/2) #rad


positionGetCommand = b'\x02\x00'
resetCommand = b'\x17\x00'

def robotGo():
    if switch.getValue() == 1:
        switch.pressed = not switch.pressed
        while switch.getValue() == 1:
            pass
        
    if switch.pressed :
        robot.forcedStop()
        return
    
    uart.write(positionGetCommand)
    #uart.write(b'\x0c\x00')
    if uart.any():
        data = uart.read()
        tagPosition = tag.getFilteredPosition(data)
        tagX = tagPosition[0]
        tagY = tagPosition[1]
        robot.computeCommand(zonePoint, tagX, tagY)
    else:
        print("no data")

while True:
    #print(f"zonePoint = {zonePoint.getX(), zonePoint.getY()}")
    robotGo()
    #robot.goStraight(0.20)
    utime.sleep(dt)

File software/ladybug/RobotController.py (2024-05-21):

import math
from machine import Pin, PWM, UART
from Point import Point
from HCSR04 import HCSR04
import gyro
import Switch
#sg90_left = PWM(Pin(21, mode = Pin.OUT))
#sg90_right = PWM(Pin(20, mode = Pin.OUT))
"""sg90_left.freq(50)
sg90_right.freq(50)
"""

gyroscope = gyro.Gyroscope()

UART_USED = 0
BAUDRATE = 115200
TX_PIN = Pin(0)
RX_PIN = Pin(1)

uart = UART(UART_USED,
            baudrate=BAUDRATE,
            tx=TX_PIN,
            rx=RX_PIN
            )

class RobotController:
    
    def __init__(self,
                 x0 = 0,
                 y0 = 0):
        
        self.x = x0
        self.y = y0
        self.robotWidth = 0.07 # m
        self.maxLinearVelocityX = 0.20 #m/s
        self.maxBackwardsLinearVelocityX = -0.20 #m/s
        self.maxAngularZDeg = 30
        self.maxAngularZRad = self.maxAngularZDeg * math.pi/180
        self.currentOrientation = 0 #rad
        self.dt = 0.1 #s
        #self.acceleration = self.maxLinearVelocityX/self.dt #m/s^2
        self.acceleration = 0.15 #m/s^2

        self.initMotors()
        self.initUART()
        self.init_PWM_values()
        
        self.leftMotorPWM = self.leftVelocityToPWM(0)
        self.rightMotorPWM = self.rightVelocityToPWM(0)
        self.currentTurnRate = 0
        self.angleError = 0
        
        self.lastAngle = 0
        self.estimatedAngleRad = 0
        
        self.offsetDistance = 0.03 #distance entre l'arrière du robot et le centre des roues.
        self.closeToPoint = False
        self.arrivedToPoint = False
        
        self.xPositionWithVelocity = x0
        self.yPositionWithVelocity = y0
        
        self.sensorRight = HCSR04(trigger_pin=7, echo_pin=6, echo_timeout_us=10000, offset=4, name = "rightSensor")
        self.sensorFront = HCSR04(trigger_pin=5, echo_pin=4, echo_timeout_us=10000, offset=0, name = "frontSensor")
        self.sensorLeft = HCSR04(trigger_pin=9, echo_pin=8, echo_timeout_us=10000, offset=0, name = "leftSensor")
        self.frontSafetyDistance = 0.10
        self.isAvoidingObstacle = False
        self.arrived = False
        
        self.velocityWanted = 0
        self.turnRateWanted = 0
        

        
    def initMotors(self,
                   rightMotorPinNumber = 20,
                   leftMotorPinNumber = 21):
        self.rightMotor = PWM(Pin(rightMotorPinNumber, mode = Pin.OUT))
        self.leftMotor = PWM(Pin(leftMotorPinNumber, mode = Pin.OUT))
        self.rightMotor.freq(50)
        self.leftMotor.freq(50)
    
    def initUART(self,
                 uart = 0,
                 baudrate = 115200,
                 txPinNumber = 0,
                 rxPinNumber = 1):
        
        self.uart = UART(uart,
                        baudrate,
                        tx=Pin(txPinNumber),
                        rx=Pin(rxPinNumber)
                        )
    def init_PWM_values(self,
                vMaxLeftPWM=8430,
                vMinLeftPWM=4990,
                vMaxRightPWM=1360,
                vMinRightPWM=4810
                ):
        
        self.vMaxLeftPWM = vMaxLeftPWM
        self.vMinLeftPWM = vMinLeftPWM
        
        self.vMaxRightPWM = vMaxRightPWM
        self.vMinRightPWM = vMinRightPWM
        
        self.backwardsMaxLeftPWM = 1354
        self.backwardsMinLeftPWM = 4789
        
        self.backwardsMaxRightPWM = 8473
        self.backwardsMinRightPWM = 5020

        
    def leftVelocityToPWM(self, vlx):
        a = (self.vMaxLeftPWM - self.vMinLeftPWM)/self.maxLinearVelocityX
        b = self.vMinLeftPWM
        #print(f"left motor PWM : {math.floor(a*vlx+b)}")
        return math.floor(a*vlx+b)
    
    def backwardsLeftVelocityToPWM(self, vlbx):
        #print("going backwards")
        a = (self.backwardsMaxLeftPWM - self.backwardsMinLeftPWM)/self.maxBackwardsLinearVelocityX
        b = self.backwardsMinLeftPWM
        #print(math.ceil(a*vlbx +b))
        return math.ceil(a*vlbx +b)
    
    def rightVelocityToPWM(self, vrx):
        
        a = (self.vMaxRightPWM - self.vMinRightPWM)/self.maxLinearVelocityX
        b = self.vMinRightPWM
        #print(f"right motor PWM : {math.ceil(a*vrx+b)}")
        return math.ceil(a*vrx+b)

    def goStraight(self, v = None):
        if v==None:
            v = self.velocityWanted
        self.rightMotorPWM = self.rightVelocityToPWM(v)
        self.leftMotorPWM = self.leftVelocityToPWM(v)
        self.leftMotor.duty_u16(self.leftMotorPWM) 
        self.rightMotor.duty_u16(self.rightMotorPWM)
    
    def turn(self,
             turnRate,
             v = 0.0):
        
        if turnRate > self.maxAngularZRad:
            turnRate = self.maxAngularZRad
            
        elif turnRate < -self.maxAngularZRad:
            turnRate = -self.maxAngularZRad
        if abs(turnRate) < 0.01:
            turnRate = 0
        vl = v - (turnRate*self.robotWidth/2)
        if v <= turnRate*self.robotWidth/2:
            self.leftMotorPWM = self.backwardsLeftVelocityToPWM(vl)
        else :
            self.leftMotorPWM = self.leftVelocityToPWM(vl)
        #vr = turnRate*self.robotWidth + vl
        vr = v + turnRate*self.robotWidth/2
        self.rightMotorPWM = self.rightVelocityToPWM(vr)
        self.leftMotor.duty_u16(self.leftMotorPWM) 
        self.rightMotor.duty_u16(self.rightMotorPWM)
        
        #self.currentTurnRate = (vr - vl) /self.robotWidth
        self.currentTurnRate = turnRate
        
    def orientTowardsPoint(self,
                         point: Point,
                         v=0.0):

        """angleStartToGoDeg = 45 #deg
        coeff = self.angleToPointDeg/(angleStartToGoDeg)
        baseTurnRate = 0.1
        turnRate = coeff*baseTurnRate"""
        pointRadius = point.getRadius()
        velocity = math.sqrt(
                            2*self.acceleration*(self.distanceToPoint - pointRadius)
                            )
        
        turnRate = 2*(self.getRightVelocity() - velocity)/self.robotWidth
        if turnRate > self.maxAngularZRad:
            turnRate = self.maxAngularZRad

        elif turnRate < -self.maxAngularZRad:
            turnRate =  -self.maxAngularZRad

        print("angleToPointDeg : ", self.angleToPointDeg)
        """if abs(self.angleToPointDeg) < 45:
            if self.distanceToPoint >= pointRadius:
                velocity = math.sqrt(
                                2*self.acceleration*(self.distanceToPoint - pointRadius)
                            )
            else:
                velocity = 0
        """
        self.turnRateWanted = turnRate
        self.velocityWanted = velocity
        #self.velocityWanted = velocity
    
    def goTowardsPoint(self, point: Point, velocity = 0.2):
        
        self.turnRateWanted = 0
        self.velocityWanted = velocity
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

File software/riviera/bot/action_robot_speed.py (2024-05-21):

"""
Module to control the speed of the main motors of the robot.
"""

from communication_codes import SPEED_LEFT, SPEED_RIGHT
import action

class ActionRobotSpeed(action.Action):
    def __init__(self, esp):
        super().__init__(esp)
        self.codeLeft = SPEED_LEFT
        self.codeRight = SPEED_RIGHT


    def execute(self, speedLeft: float, speedRight: float):
        """
        Set the speed of the main motors of the robot.
        
        Inputs are floats between -1 and 1 in m/s.
        """
        trame = [self.codeLeft, int((speedLeft+1)*100), self.codeRight, int((speedRight+1)*100)]
        self.get_communicator().send_trame(trame)

    def stop(self):
        """Stop the robot."""
        return self.execute(0, 0)

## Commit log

2023-11-19 Added Gantt planning, robot's estimated weight, and reports folder
    [Estimated_weight_main_robot.xlsx]
2024-02-16 Added Loic's and Adrien's 9 first reports
    [support moteur + tendeur.STL, support pivot.stl]
2024-05-06 big commit
    [dataimages.20.csv]
